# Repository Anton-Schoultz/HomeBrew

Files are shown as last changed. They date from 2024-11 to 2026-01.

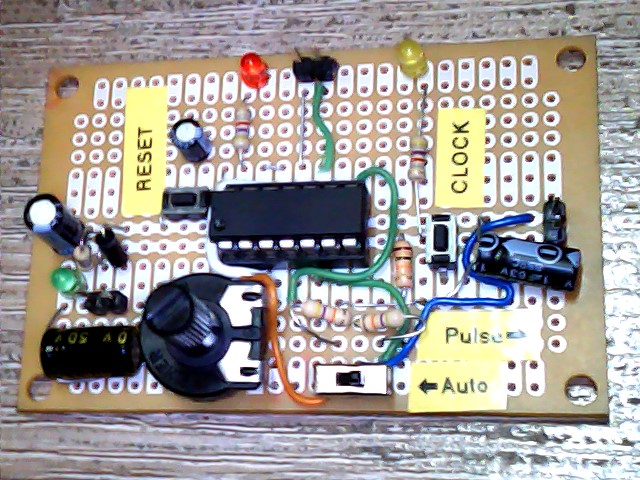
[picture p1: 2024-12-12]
Development/ClockCircuit/ClockCircuit.jpg

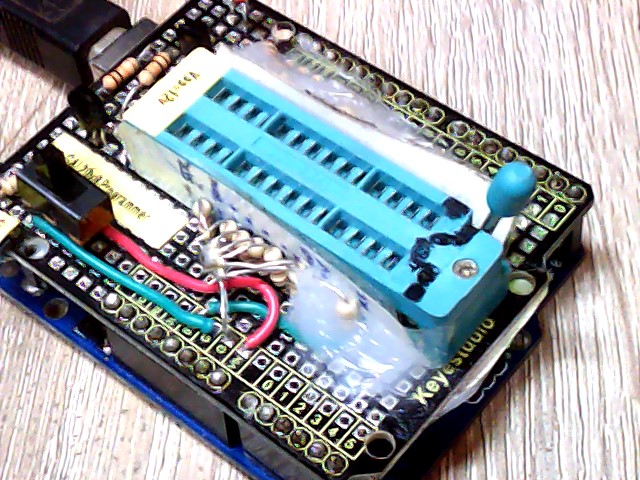
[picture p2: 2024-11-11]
Tools/GAL_Programmer/GAL_Programmer_Hat.jpg

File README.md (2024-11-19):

# HomeBrew
My attempt at rolling-my-own reto 80's home computer.

Aiming for a 6502 (specifically R65C02) based system,
ideally with video output.

# Tools
Here I have collected the various tools that I needed.
<br>See the README.md in the tools folder for more info.

## EE Programmer
Used to program the EEPROM that I use, the PQ 52B33, which is an 8K rom. 
Programmed via an arduino circuit, using java code on the pc side.

## GAL Programmer
Used to program the GAL20V8s that I use (available and affordable here).
<br>Bassed on the Afterburner project by Bruce Abbott.
<br>I added some convenience batch jobs GAL_Write.bat and GAL_Read.bat.

## Logic Analyser
Here I made use of the excellent PulseView Program,
using a Raspberry Pi Pico as the data capture device.

## WinCUPL
This outdated program from ATMEL is used to compile the fuse info for
programming the GAL20V8 chips.

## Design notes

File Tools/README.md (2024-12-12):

# Tools
A collection of the tools used for this project.

## GAL Programmer
The GAL programmer is bassed on this project by Bruce Abbott
https://github.com/ole00/afterburner/tree/version_4_legacy

## WinCUPL
This is used to program the GAL20v8 chips.

## Logic Analyser
Here I made use of the excellent PulseView Program,
using a Raspberry Pi Pico as the data capture device.

## EE Programmer
Simple DIY EEPROM programer for PQ 52B33 8k x 8 EEPROM (Using Arduino Nano)

## KiCAD
Schematic and PCB editor.

## IC Label Creator
This useful utility (from https://github.com/klemens-u/ic-label-creator) lets you print out IC-Labels.
You can define your own ICs and add them to the chips.js file.
I made some code changes so that it will print narrower to fit on top of the IC nicely,
also some changes to allow you to select your own border colour for the IC label.
I added IC pinouts for R65C02 (Cpu), 52B33 (8k EEPROM) ...

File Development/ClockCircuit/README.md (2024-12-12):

# Retro Computer
When I started on this journey to build my own retro computer I first looked to see what others had done.
I found Ben Eater's videos extremely useful.
I like his aproach to building his 6502 machine, and will most likely proceed in a similar fasion.

## Clock Circuit
After seeing the usefulness of Ben's clock circuit https://eater.net/8bit/clock, I opted to make my own.

I opted for a somewhat different (cruder) circuit, and added a reset circuit.

<image src="ClockCircuit.jpg"/>

Please excuse the hand-drawn diagram, but I figure even a badly hand drawn diagram is better than no diagram at all ;-)

The negative going reset pulse is generated at power-up, but can also be triggered by the push button.
<br>The positive going clock pulses can be manually generated, or auto-generated via a variable speed oscillator.
<br>It would probably be a good idea to add a 1K resistor in series with the variable resistor for safety..

<image src="CircuitDiagram.png"/>

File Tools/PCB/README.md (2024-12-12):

# KiCAD
Schematic and PCB editor.
Download the latest version from https://www.kicad.org/download/
(In my case, 8.0.6)

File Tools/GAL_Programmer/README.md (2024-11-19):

# GAL Programmer
The GAL programmer is bassed on this project by Bruce Abbott
https://github.com/ole00/afterburner/tree/version_4_legacy

<image src="afterburner_circuit.png"/>

The PC code is <a href="afterburner_w64_040.exe">afterburner w64 v4.0</a>
and the code for th Arduino UNO is <a href="afterburner042/afterburner042.ino">afterburner042.ino</a>

Links:
<br>https://www.youtube.com/watch?v=fCsP7ujMJV8

I used a circuit based on the one in the video (at 8:15)
to switch the 12v supply to the edit pin instead of the switchable module.

I thew it all together on a proto-typing 'hat' which then plugs onto the Arduino UNO R3.

<image src="GAL_Programmer_Hat.jpg"/>

<br>I added some convenience batch jobs GAL_Write.bat and GAL_Read.bat.

See also the section on WinCUPL (used to compile the descriptions)

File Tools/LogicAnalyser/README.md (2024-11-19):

# Logic Analyser
Here I made use of the excellent PulseView Program,
using a Raspberry Pi Pico as the data capture device.

*Raspberry Pi Install*

Hold down the button, plug it in, release the button.
It will appear as a USB drive, drag and drop this file
<code>pico_sdk_sigrok.uf2</code> into the folder to install the software
onto the Raspberry Pi.

As the Pi is 3v3 and I'm working with 5v circuits, I built a little adaptor board
with voltage dividers for the input pins.
I used 3k3 resistor in line, with a 4k7 to ground.

<image src="Pi-Pico-adapter-board.jpg"/>

I used the nightly builds as they include the Raspberry Pi capture device.
(The release version does not show it in the device dropdown)<ul>
<li><a href="pulseview-NIGHTLY-x86_64-release-installer.exe">Pulse View</a>
<li><a href="sigrok-cli-NIGHTLY-x86_64-release-installer.exe">Sigrok</a>
</ul>

Links: 
<br>https://www.youtube.com/watch?app=desktop&v=waBu6ijT3wo
<br>https://github.com/pysigrok/hardware-raspberrypi-pico

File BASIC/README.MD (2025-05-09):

<html><body>
<h1>BASIC 	KEYWORDS</H1>
<dl 		COMPACT>
<dt> 		ABS(##)<DD>RETURN absolute value of numeric expression ##
<dt> 		ASC($$)<DD>RETURN numeric value of the first character of String $$
<dt> 		CHR$(##)<DD>RETURN string with a character for the given value
<dt> 		CLEAR<DD>CLEAR variables
<dt> 		CLS<DD>CLEAR Screen
<dt> 		DEEK(##)<DD>RETURN the contents of memory word at address
<dt> 		dim 	a$(##size) [,b$(##size)]*<dd>Dimension Strings
<dt> 		DOKE 	##Address,##word<dd>Poke word of data to the address
<dt> 		for 	#V = ##From TO ##Limit [STEP ##Step]<dd>Start of FOR/NEXT Loop
<dt> 		FRE(##)<DD>RETURN number of bytes available in free memory
<dt> 		STR$(##Value)<DD>RETURN string representation of the value
<dt> 		GOSUB 	#expr<dd>Call subroutine at LineNo
<dt> 		GOTO 	#NumExpr<dd>Goto LineNo
<dt> 		IF 	?? THEN {Statment}<dd>Execute statement if condition ?? is true
<dt> 		DO 	string comparison
<dt> 		INPUT 	("prompt"|,|NumVar|StrVar)*<dd>Input values with optional prompts
<dt> 		LEFT$($$,##)<DD>KEEP left most chars of string [Head]
<dt> 		LEN($$)<DD>RETURN the length of the string expression
<dt> 		let 	{var}={expr}<dd>Assign value to a variable
<dt> 		LIST 	[##From] [- [##To]]<dd>List program (optional range of lines)
<dt> 		LIST 	lines in range LST_BEG to LST_END
<dt> 		LOAD<DD>LOAD program
<dt> 		LOWER($$)<DD>CONVERT string to Lower case
<dt> 		LTRIM($$)<DD>TRIM leading spaces from string
<dt> 		MID$($$,##From,##Len)<DD>RETURN substring of Len chars from position From
<dt> 		NEW<DD>CLEAR program and data
<dt> 		NEXT 	{Var}<dd>End of FOR/NEXT loop
<dt> 		PEEK(##Address)<DD>RETURN the byte at address
<dt> 		POKE 	##Address,##value<dd>Poke byte of data to the address
<dt> 		PRINT 	(##|$$| |,)*<dd>Print sequence of values
<dt> 		rem 	{comment}<dd>Program remarks/comments
<dt> 		RETURN<DD>RETURN control to after the GOSUB
<dt> 		RIGHT$($$,##N)<DD>KEEP right most N chars of string [Tail]
<dt> 		RND(##Max)<DD>RETURN random number 0..(##Max-)
<dt> 		RTRIM$($$)<DD>TRIM trailing spaces from string
<dt> 		run 	[#LineNo]<dd>Execute the program, optionally from line number
<dt> 		SAVE<DD>SAVE program
<dt> 		SGN(##Value)<DD>RETURN sign of the value as  -1, 0 or 1
<dt> 		SQR(##Val)<DD>RETURN the Square of Val
<dt> 		STOP<DD>STOP executing the program
<dt> 		TRIM$($$)<DD>TRIM leading and trailing spaces from the string
<dt> 		UPPER$($$)<DD>CONVERT string to upper case
<dt> 		VAL($$)<DD>EVALUATE the string and return it's numeric value
</dl>
<br>$$=String 	EXPRESSION
<br>##=Numeric 	EXPRESSION
<br>#=Numeric 	LITERAL
<br>$=String 	LITERAL (Quoted string)
<br>??=Relational/Conditional EXPRESSION
</body>
</html>

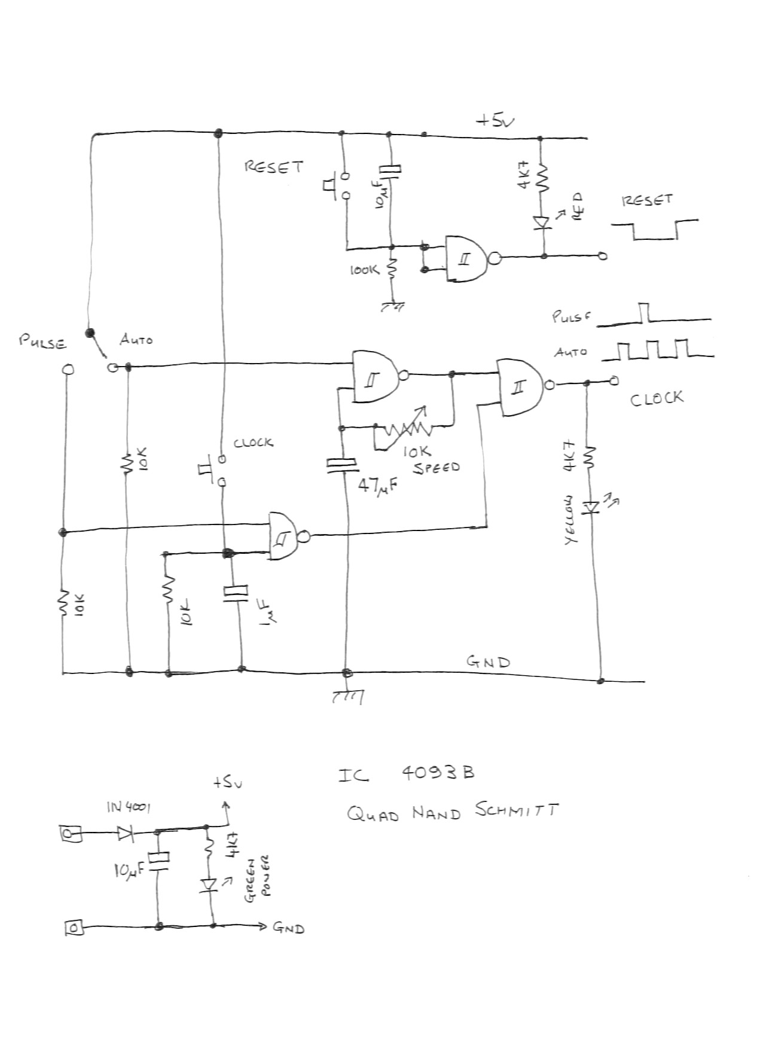
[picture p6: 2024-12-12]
Development/ClockCircuit/CircuitDiagram.png

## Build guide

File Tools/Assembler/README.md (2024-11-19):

# Assembler
I use <a href="https://jorgicor.niobe.org/uz80as/">this</a>
assembler (originally for Z80) but has R65C02 as a valid target.
I use Ultra Edit as the editor, and add 'Tools' to call the assembler as needed.

## Simulator
There is also a 6502 based IDE including a simulator,
See 6502_Simulator section

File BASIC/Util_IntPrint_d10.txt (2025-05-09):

;=================================================================== UTIL_INT ========= 
; IntParse:; parse an integer
IntPrint: ; Print integer AX to mem/io via PutChr
; 65535:2276c, 10000:2246, 1000:1781
 		sta 	ZTMP
 		stx 	ZTMP+1
 		ldy 	#$FF
 		phy 				; marker on the stack
IntPrint1 	jsr 	IntDT 			; ZTMP /= 10, remainder in A
 		ora 	#'0'
 		pha 				; push the digit
 		lda 	ZTMP 			; done?
 		ora 	ZTMP+1
 		bne 	IntPrint1 		; no- loop
 		;-- 
IntPrint2 	;- now pop & print the digits
 		pla
 		bmi 	IntPrintX 		; found the marker so exit
 		jsr 	PutChr
 		bra 	IntPrint2
IntPrintX 	rts

;------------------------------------------------------- IntDT_AX 
IntDT_AX: ; Divide AX by 10, result in ZTMP, remainder in A
 		sta 	ZTMP
 		stx 	ZTMP+1
 		;-- fall through
IntDT: ; Divide ZTMP by 10, remainder in A
 		ldx 	#16
 		lda 	#0
IntDT_AX1 	asl 	ZTMP
 		rol 	ZTMP+1
 		rol 	a
 		cmp 	#10
 		bcc 	IntDT_AX2
 		sbc 	#10
 		inc 	ZTMP
IntDT_AX2 	dex
 		bne 	IntDT_AX1
 		rts

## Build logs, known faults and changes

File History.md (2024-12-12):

# History

## 2024

**October**
GAL Programmer, WinCUPL
Simple EE prgrammer on breadboard.

**November**
Assembler, 6502 Simulator, PCB software (KiCAD)

**December**
Logic Analyser.
<br>Built my clock circuit
<br>some test code on Arduino Mega to 'talk' to a 240x128 LCD screen.

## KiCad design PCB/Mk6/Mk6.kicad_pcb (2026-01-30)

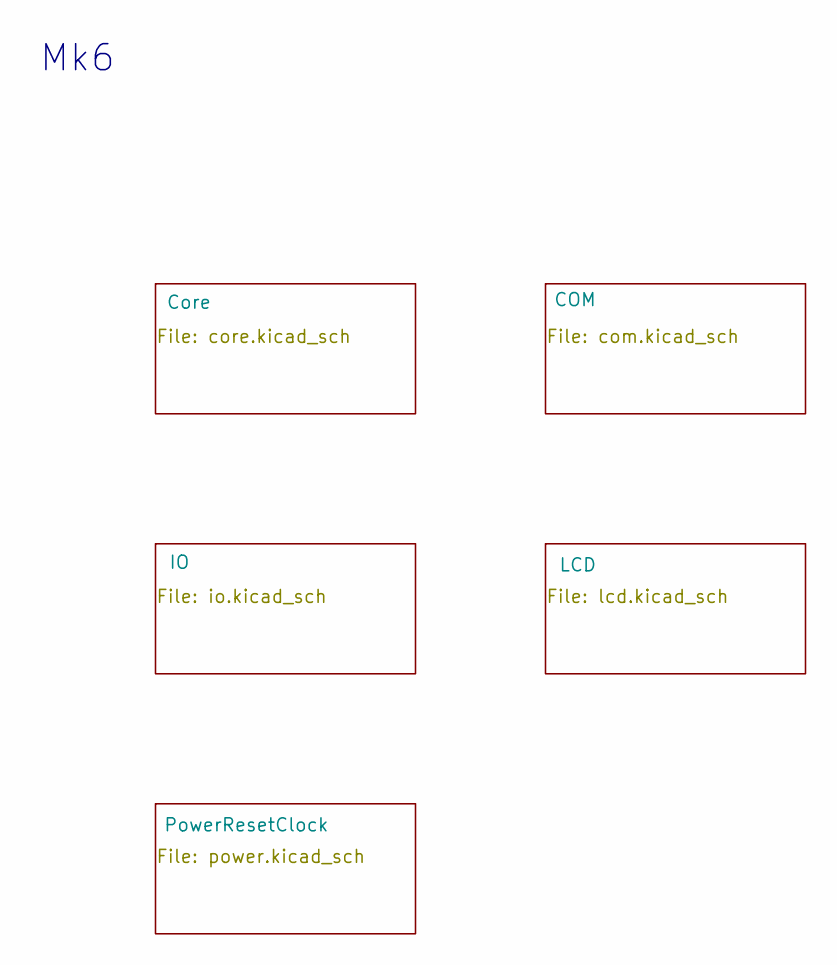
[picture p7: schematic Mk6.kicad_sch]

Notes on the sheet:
Mk6

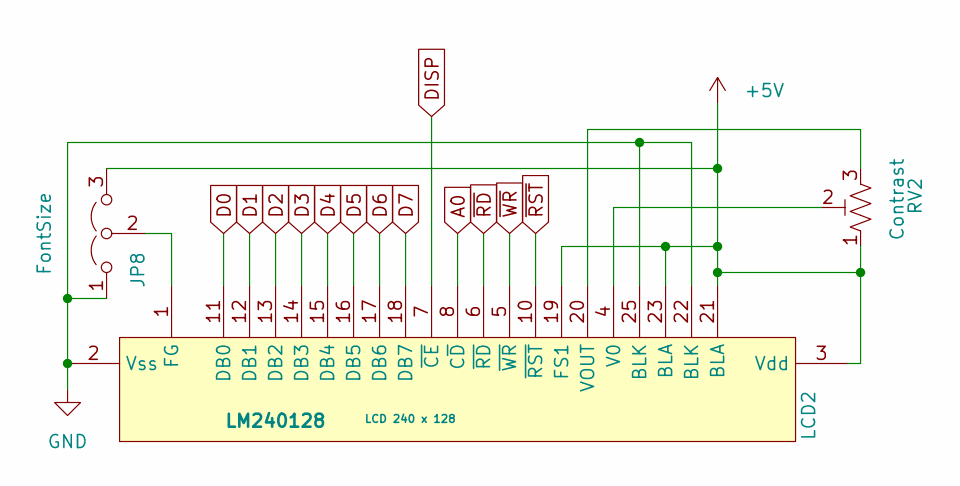
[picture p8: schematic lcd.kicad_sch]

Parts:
JP8: FontSize; PinHeader_1x03_P2.54mm_Vertical
LCD2: LM240128; LCD 240x128
RV2: Contrast; Potentiometer_Piher_PT-15-V15_Vertical

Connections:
+5V: JP8.3 (B), LCD2.3 (Vdd), LCD2.19 (FS1), LCD2.21 (BLA), LCD2.23 (BLA), RV2.1; also elsewhere on the board
A0: LCD2.8 (C~D); also elsewhere on the board
D0: LCD2.11 (DB0); also elsewhere on the board
D1: LCD2.12 (DB1); also elsewhere on the board
D2: LCD2.13 (DB2); also elsewhere on the board
D3: LCD2.14 (DB3); also elsewhere on the board
D4: LCD2.15 (DB4); also elsewhere on the board
D5: LCD2.16 (DB5); also elsewhere on the board
D6: LCD2.17 (DB6); also elsewhere on the board
D7: LCD2.18 (DB7); also elsewhere on the board
DISP: LCD2.7 (~CE); also elsewhere on the board
GND: JP8.1 (A), LCD2.2 (Vss), LCD2.22 (BLK), LCD2.25 (BLK); also elsewhere on the board
unnamed: JP8.2 (C), LCD2.1 (FG)
unnamed: LCD2.4 (V0), RV2.2
unnamed: LCD2.20 (VOUT), RV2.3
~RD: LCD2.6 (~RD); also elsewhere on the board
~RST: LCD2.10 (~RST); also elsewhere on the board
~WR: LCD2.5 (~WR); also elsewhere on the board

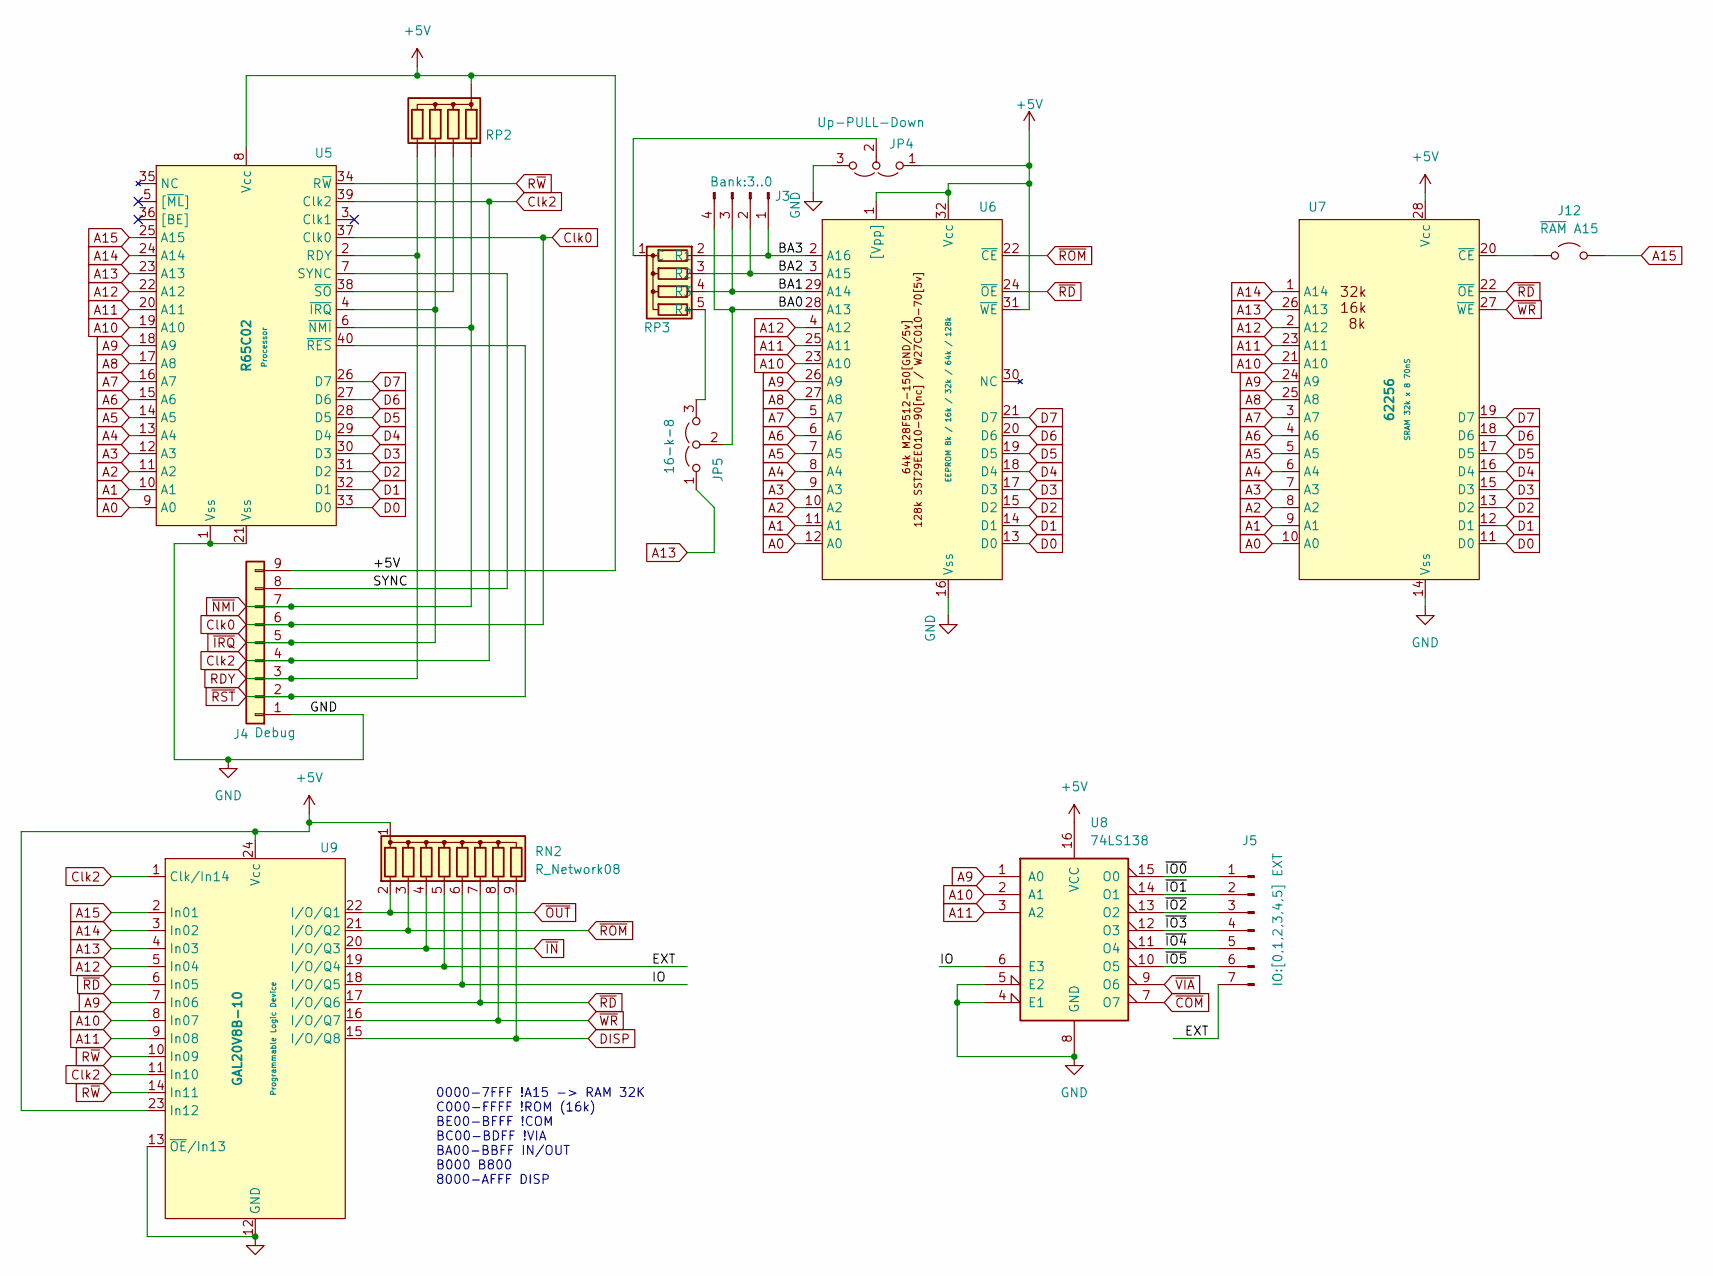
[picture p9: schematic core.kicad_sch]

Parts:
J3: Bank:3..0; PinHeader_1x04_P2.54mm_Vertical
J4: Debug; PinHeader_1x09_P2.54mm_Vertical
J5: IO:[0,1,2,3,4,5] EXT; PinSocket_1x07_P2.54mm_Vertical
J12: ~{RAM} A15; PinHeader_1x02_P2.54mm_Vertical
JP4: Up-PULL-Down; PinHeader_1x03_P2.54mm_Vertical
JP5: 16-k-8; PinHeader_1x03_P2.54mm_Vertical
RN2: R_Network08; R_Array_SIP9
RP2, RP3: R_Array_SIP5
U5: R65C02; DIP-40_W15.24mm_LongPads
U6: EEPROM; DIP_Socket-32_W11.9_W12.7_W15.24_W17.78_W18.5_3M_232-1285-0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
U7: 62256; DIP-28_W15.24mm_LongPads
U8: 74LS138; DIP-16_W7.62mm_LongPads
U9: GAL20V8B-10; DIP-24_W7.62mm_LongPads

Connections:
+5V: J4.9, JP4.1 (A), RN2.1 (common), RP2.1 (C), U5.8 (Vcc), U6.1 ([Vpp]), U6.31 (~WE), U6.32 (Vcc), U7.28 (Vcc), U8.16 (VCC), U9.23 (In12), U9.24 (Vcc); also elsewhere on the board
/Core/BA0: J3.4, JP5.2 (C), U6.28 (A13)
/Core/BA1: J3.3, RP3.4 (R3), U6.29 (A14)
/Core/BA2: J3.2, RP3.3 (R2), U6.3 (A15)
/Core/BA3: J3.1, RP3.2 (R1), U6.2 (A16)
/Core/EXT: J5.7, RN2.5 (R4), U9.19 (I/O/Q4)
/Core/IO: RN2.6 (R5), U8.6 (E3), U9.18 (I/O/Q5)
/Core/SYNC: J4.8, U5.7 (SYNC)
/Core/~IO0: J5.1, U8.15 (O0)
/Core/~IO1: J5.2, U8.14 (O1)
/Core/~IO2: J5.3, U8.13 (O2)
/Core/~IO3: J5.4, U8.12 (O3)
/Core/~IO4: J5.5, U8.11 (O4)
/Core/~IO5: J5.6, U8.10 (O5)
A0: U5.9 (A0), U6.12 (A0), U7.10 (A0); also elsewhere on the board
A1: U5.10 (A1), U6.11 (A1), U7.9 (A1); also elsewhere on the board
A2: U5.11 (A2), U6.10 (A2), U7.8 (A2); also elsewhere on the board
A3: U5.12 (A3), U6.9 (A3), U7.7 (A3); also elsewhere on the board
A4: U5.13 (A4), U6.8 (A4), U7.6 (A4); also elsewhere on the board
A5: U5.14 (A5), U6.7 (A5), U7.5 (A5); also elsewhere on the board
A6: U5.15 (A6), U6.6 (A6), U7.4 (A6); also elsewhere on the board
A7: U5.16 (A7), U6.5 (A7), U7.3 (A7); also elsewhere on the board
A8: U5.17 (A8), U6.27 (A8), U7.25 (A8); also elsewhere on the board
A9: U5.18 (A9), U6.26 (A9), U7.24 (A9), U8.1 (A0), U9.7 (In06); also elsewhere on the board
A10: U5.19 (A10), U6.23 (A10), U7.21 (A10), U8.2 (A1), U9.8 (In07); also elsewhere on the board
A11: U5.20 (A11), U6.25 (A11), U7.23 (A11), U8.3 (A2), U9.9 (In08); also elsewhere on the board
A12: U5.22 (A12), U6.4 (A12), U7.2 (A12), U9.5 (In04); also elsewhere on the board
A13: JP5.1 (A), U5.23 (A13), U7.26 (A13), U9.4 (In03)
A14: U5.24 (A14), U7.1 (A14), U9.3 (In02)
A15: J12.2 (B), U5.25 (A15), U9.2 (In01)
Clk0: J4.6, U5.37 (Clk0); also elsewhere on the board
Clk2: J4.4, U5.39 (Clk2), U9.1 (Clk/In14), U9.11 (In10); also elsewhere on the board
D0: U5.33 (D0), U6.13 (D0), U7.11 (D0); also elsewhere on the board
D1: U5.32 (D1), U6.14 (D1), U7.12 (D1); also elsewhere on the board
D2: U5.31 (D2), U6.15 (D2), U7.13 (D2); also elsewhere on the board
D3: U5.30 (D3), U6.17 (D3), U7.15 (D3); also elsewhere on the board
D4: U5.29 (D4), U6.18 (D4), U7.16 (D4); also elsewhere on the board
D5: U5.28 (D5), U6.19 (D5), U7.17 (D5); also elsewhere on the board
D6: U5.27 (D6), U6.20 (D6), U7.18 (D6); also elsewhere on the board
D7: U5.26 (D7), U6.21 (D7), U7.19 (D7); also elsewhere on the board
DISP: RN2.9 (R8), U9.15 (I/O/Q8); also elsewhere on the board
GND: J4.1, JP4.3 (B), U5.1 (Vss), U5.21 (Vss), U6.16 (Vss), U7.14 (Vss), U8.4 (E1), U8.5 (E2), U8.8 (GND), U9.12 (GND), U9.13 (~OE/In13); also elsewhere on the board
unnamed: J12.1 (A), U7.20 (~CE)
unnamed: JP4.2 (C), RP3.1 (C)
unnamed: JP5.3 (B), RP3.5 (R4)
unnamed: RP2.3 (R2), U5.38 (~SO)
RDY: J4.3, RP2.5 (R4), U5.2 (RDY); also elsewhere on the board
R~W: U5.34 (R~W), U9.10 (In09), U9.14 (In11); also elsewhere on the board
~COM: U8.7 (O7); also elsewhere on the board
~IN: RN2.4 (R3), U9.20 (I/O/Q3); also elsewhere on the board
~IRQ: J4.5, RP2.4 (R3), U5.4 (~IRQ); also elsewhere on the board
~NMI: J4.7, RP2.2 (R1), U5.6 (~NMI); also elsewhere on the board
~OUT: RN2.2 (R1), U9.22 (I/O/Q1); also elsewhere on the board
~RD: RN2.7 (R6), U6.24 (~OE), U7.22 (~OE), U9.6 (In05), U9.17 (I/O/Q6); also elsewhere on the board
~ROM: RN2.3 (R2), U6.22 (~CE), U9.21 (I/O/Q2)
~RST: J4.2, U5.40 (~RES); also elsewhere on the board
~VIA: U8.9 (O6); also elsewhere on the board
~WR: RN2.8 (R7), U7.27 (~WE), U9.16 (I/O/Q7); also elsewhere on the board

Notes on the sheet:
0000-7FFF !A15 -> RAM 32K C000-FFFF !ROM (16k) BE00-BFFF !COM BC00-BDFF !VIA BA00-BBFF IN/OUT B000 B800 8000-AFFF DISP

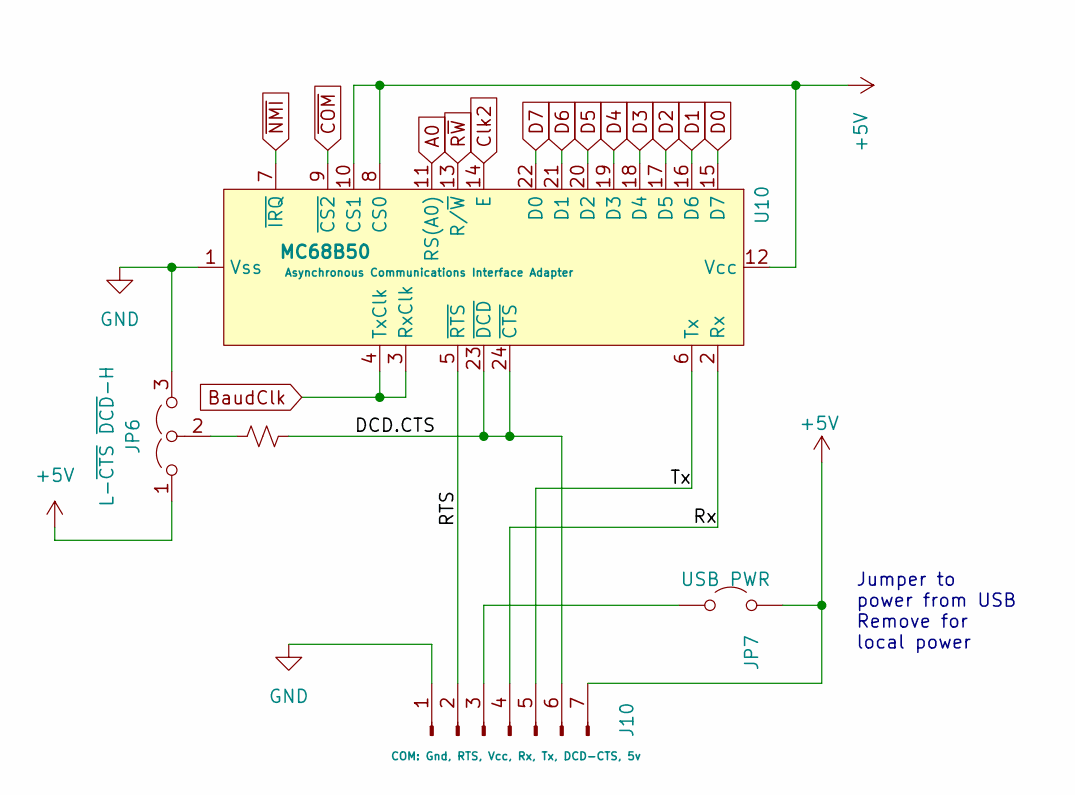
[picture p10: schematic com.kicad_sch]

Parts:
J10: COM: Gnd, RTS, Vcc, Rx, Tx, DCD-CTS, 5v; PinSocket_1x07_P2.54mm_Horizontal
JP6: L-~{CTS} ~{DCD}-H; PinHeader_1x03_P2.54mm_Vertical
JP7: USB PWR; PinHeader_1x02_P2.54mm_Vertical
R4: PUp; R_Axial_DIN0204_L3.6mm_D1.6mm_P7.62mm_Horizontal
U10: MC68B50; DIP-24_W15.24mm_LongPads

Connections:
+5V: J10.7, JP6.1 (A), JP7.2 (B), U10.8 (CS0), U10.10 (CS1), U10.12 (Vcc); also elsewhere on the board
/COM/DCD.CTS: J10.6, R4.2, U10.23 (~DCD), U10.24 (~CTS)
/COM/RTS: J10.2, U10.5 (~RTS)
/COM/Rx: J10.4, U10.2 (Rx)
/COM/Tx: J10.5, U10.6 (Tx)
A0: U10.11 (RS(A0)); also elsewhere on the board
BaudClk: U10.3 (RxClk), U10.4 (TxClk); also elsewhere on the board
Clk2: U10.14 (E); also elsewhere on the board
D0: U10.15 (D7); also elsewhere on the board
D1: U10.16 (D6); also elsewhere on the board
D2: U10.17 (D5); also elsewhere on the board
D3: U10.18 (D4); also elsewhere on the board
D4: U10.19 (D3); also elsewhere on the board
D5: U10.20 (D2); also elsewhere on the board
D6: U10.21 (D1); also elsewhere on the board
D7: U10.22 (D0); also elsewhere on the board
GND: J10.1, JP6.3 (B), U10.1 (Vss); also elsewhere on the board
unnamed: J10.3, JP7.1 (A)
unnamed: JP6.2 (C), R4.1
R~W: U10.13 (R/~W); also elsewhere on the board
~COM: U10.9 (~CS2); also elsewhere on the board
~NMI: U10.7 (~IRQ); also elsewhere on the board

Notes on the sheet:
Jumper to power from USB Remove for local power

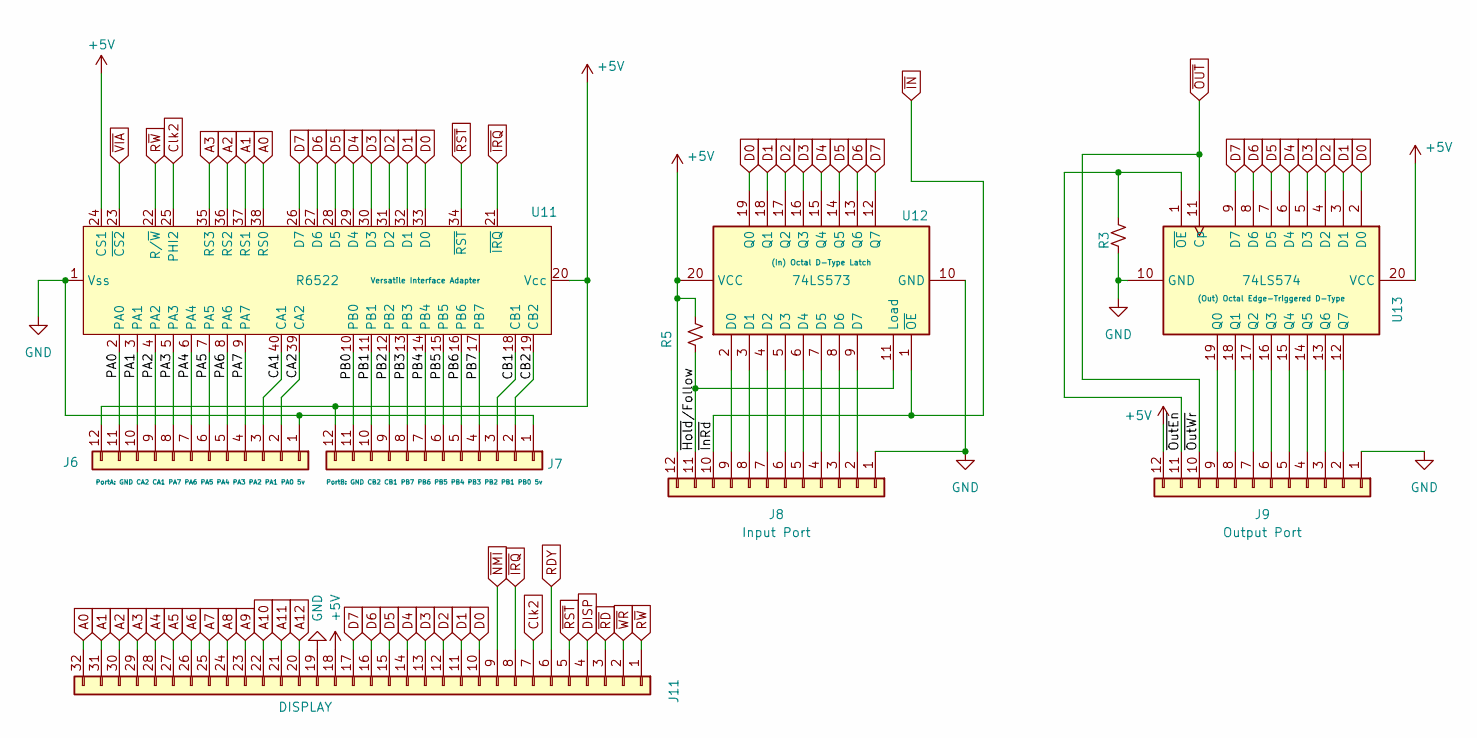
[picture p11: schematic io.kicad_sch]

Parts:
J6: PortA: GND CA2 CA1 PA7 PA6 PA5 PA4 PA3 PA2 PA1 PA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; PinSocket_1x12_P2.54mm_Vertical
J7: PortB: GND CB2 CB1 PB7 PB6 PB5 PB4 PB3 PB2 PB1 PB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; PinSocket_1x12_P2.54mm_Vertical
J8: Input Port; PinHeader_1x12_P2.54mm_Vertical
J9: Output Port; PinHeader_1x12_P2.54mm_Vertical
J11: DISPLAY; PinSocket_1x32_P2.54mm_Vertical
R3, R5: R_Small_US; R_Axial_DIN0204_L3.6mm_D1.6mm_P7.62mm_Horizontal
U11: R6522; DIP-40_W15.24mm_LongPads
U12: 74LS573; DIP-20_W7.62mm_LongPads
U13: 74LS574; DIP-20_W7.62mm_LongPads

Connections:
+5V: J6.12, J7.12, J8.12, J9.12, J11.18, R5.1, U11.20 (Vcc), U11.24 (CS1), U12.20 (VCC), U13.20 (VCC); also elsewhere on the board
/IO/CA1: J6.3, U11.40 (CA1)
/IO/CA2: J6.2, U11.39 (CA2)
/IO/CB1: J7.3, U11.18 (CB1)
/IO/CB2: J7.2, U11.19 (CB2)
/IO/PA0: J6.11, U11.2 (PA0)
/IO/PA1: J6.10, U11.3 (PA1)
/IO/PA2: J6.9, U11.4 (PA2)
/IO/PA3: J6.8, U11.5 (PA3)
/IO/PA4: J6.7, U11.6 (PA4)
/IO/PA5: J6.6, U11.7 (PA5)
/IO/PA6: J6.5, U11.8 (PA6)
/IO/PA7: J6.4, U11.9 (PA7)
/IO/PB0: J7.11, U11.10 (PB0)
/IO/PB1: J7.10, U11.11 (PB1)
/IO/PB2: J7.9, U11.12 (PB2)
/IO/PB3: J7.8, U11.13 (PB3)
/IO/PB4: J7.7, U11.14 (PB4)
/IO/PB5: J7.6, U11.15 (PB5)
/IO/PB6: J7.5, U11.16 (PB6)
/IO/PB7: J7.4, U11.17 (PB7)
/IO/~Hold/Follow: J8.11, R5.2, U12.11 (Load)
/IO/~OutEn: J9.11, R3.2, U13.1 (~OE)
A0: J11.32, U11.38 (RS0); also elsewhere on the board
A1: J11.31, U11.37 (RS1); also elsewhere on the board
A2: J11.30, U11.36 (RS2); also elsewhere on the board
A3: J11.29, U11.35 (RS3); also elsewhere on the board
A4: J11.28; also elsewhere on the board
A5: J11.27; also elsewhere on the board
A6: J11.26; also elsewhere on the board
A7: J11.25; also elsewhere on the board
A8: J11.24; also elsewhere on the board
A9: J11.23; also elsewhere on the board
A10: J11.22; also elsewhere on the board
A11: J11.21; also elsewhere on the board
A12: J11.20; also elsewhere on the board
Clk2: J11.7, U11.25 (PHI2); also elsewhere on the board
D0: J11.10, U11.33 (D0), U12.19 (Q0), U13.2 (D0); also elsewhere on the board
D1: J11.11, U11.32 (D1), U12.18 (Q1), U13.3 (D1); also elsewhere on the board
D2: J11.12, U11.31 (D2), U12.17 (Q2), U13.4 (D2); also elsewhere on the board
D3: J11.13, U11.30 (D3), U12.16 (Q3), U13.5 (D3); also elsewhere on the board
D4: J11.14, U11.29 (D4), U12.15 (Q4), U13.6 (D4); also elsewhere on the board
D5: J11.15, U11.28 (D5), U12.14 (Q5), U13.7 (D5); also elsewhere on the board
D6: J11.16, U11.27 (D6), U12.13 (Q6), U13.8 (D6); also elsewhere on the board
D7: J11.17, U11.26 (D7), U12.12 (Q7), U13.9 (D7); also elsewhere on the board
DISP: J11.4; also elsewhere on the board
GND: J6.1, J7.1, J8.1, J9.1, J11.19, R3.1, U11.1 (Vss), U12.10 (GND), U13.10 (GND); also elsewhere on the board
unnamed: J8.2, U12.9 (D7)
unnamed: J8.3, U12.8 (D6)
unnamed: J8.4, U12.7 (D5)
unnamed: J8.5, U12.6 (D4)
unnamed: J8.6, U12.5 (D3)
unnamed: J8.7, U12.4 (D2)
unnamed: J8.8, U12.3 (D1)
unnamed: J8.9, U12.2 (D0)
unnamed: J9.2, U13.12 (Q7)
unnamed: J9.3, U13.13 (Q6)
unnamed: J9.4, U13.14 (Q5)
unnamed: J9.5, U13.15 (Q4)
unnamed: J9.6, U13.16 (Q3)
unnamed: J9.7, U13.17 (Q2)
unnamed: J9.8, U13.18 (Q1)
unnamed: J9.9, U13.19 (Q0)
RDY: J11.6; also elsewhere on the board
R~W: J11.1, U11.22 (R/~W); also elsewhere on the board
~IN: J8.10, U12.1 (~OE); also elsewhere on the board
~IRQ: J11.8, U11.21 (~IRQ); also elsewhere on the board
~NMI: J11.9; also elsewhere on the board
~OUT: J9.10, U13.11 (Cp); also elsewhere on the board
~RD: J11.3; also elsewhere on the board
~RST: J11.5, U11.34 (~RST); also elsewhere on the board
~VIA: U11.23 (~CS2); also elsewhere on the board
~WR: J11.2; also elsewhere on the board

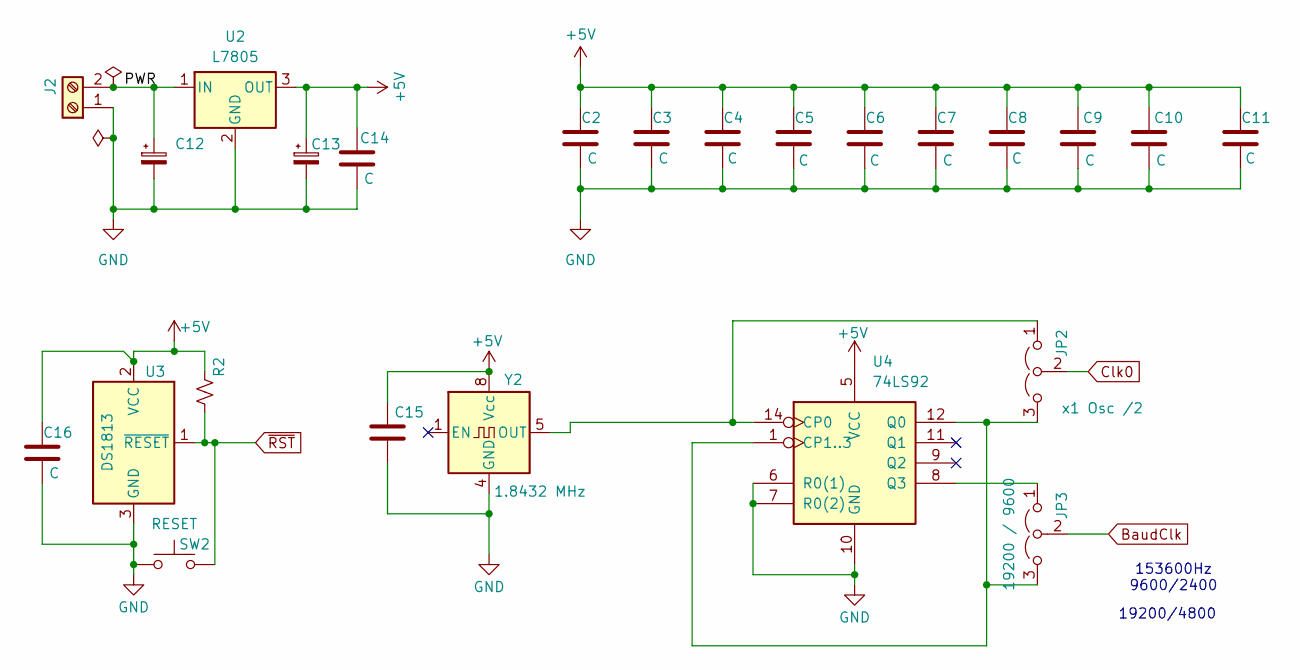
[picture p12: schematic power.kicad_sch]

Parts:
C2, C3, C4, C5, C6, C7, C8, C9, C10, C11, C14, C15, C16: C; C_Disc_D7.5mm_W2.5mm_P5.00mm
C12, C13: C_Polarized_Small; CP_Radial_D10.0mm_P7.50mm
J2: Power; TerminalBlock_MaiXu_MX126-5.0-02P_1x02_P5.00mm
JP2: x1 Osc /2; PinHeader_1x03_P2.54mm_Vertical
JP3: 19200 / 9600; PinHeader_1x03_P2.54mm_Vertical
R2: R_Small_US; R_Axial_DIN0204_L3.6mm_D1.6mm_P7.62mm_Horizontal
SW2: RESET; SW_PUSH_1P1T_6x3.5mm_H4.3_APEM_MJTP1243
U2: L7805; TO-220-3_Vertical
U3: DS1813; TO-92L_Wide
U4: 74LS92; DIP-14_W7.62mm_LongPads
Y2: 1.8432 MHz; Oscillator_DIP-8

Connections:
+5V: C2.1, C3.1, C4.1, C5.1, C6.1, C7.1, C8.1, C9.1, C10.1, C11.1, C13.1, C14.1, C15.1, C16.1, R2.1, U2.3 (OUT), U3.2 (VCC), U4.5 (VCC), Y2.8 (Vcc); also elsewhere on the board
/PowerResetClock/PWR: C12.1, J2.2, U2.1 (IN)
BaudClk: JP3.2 (C); also elsewhere on the board
Clk0: JP2.2 (C); also elsewhere on the board
GND: C2.2, C3.2, C4.2, C5.2, C6.2, C7.2, C8.2, C9.2, C10.2, C11.2, C12.2, C13.2, C14.2, C15.2, C16.2, J2.1, SW2.1, U2.2 (GND), U3.3 (GND), U4.6 (R0(1)), U4.7 (R0(2)), U4.10 (GND), Y2.4 (GND); also elsewhere on the board
unnamed: JP2.1 (A), U4.14 (CP0), Y2.5 (OUT)
unnamed: JP2.3 (B), JP3.3 (B), U4.1 (CP1..3), U4.12 (Q0)
unnamed: JP3.1 (A), U4.8 (Q3)
~RST: R2.2, SW2.2, U3.1 (~RESET); also elsewhere on the board

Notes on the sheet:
153600Hz 9600/2400
19200/4800

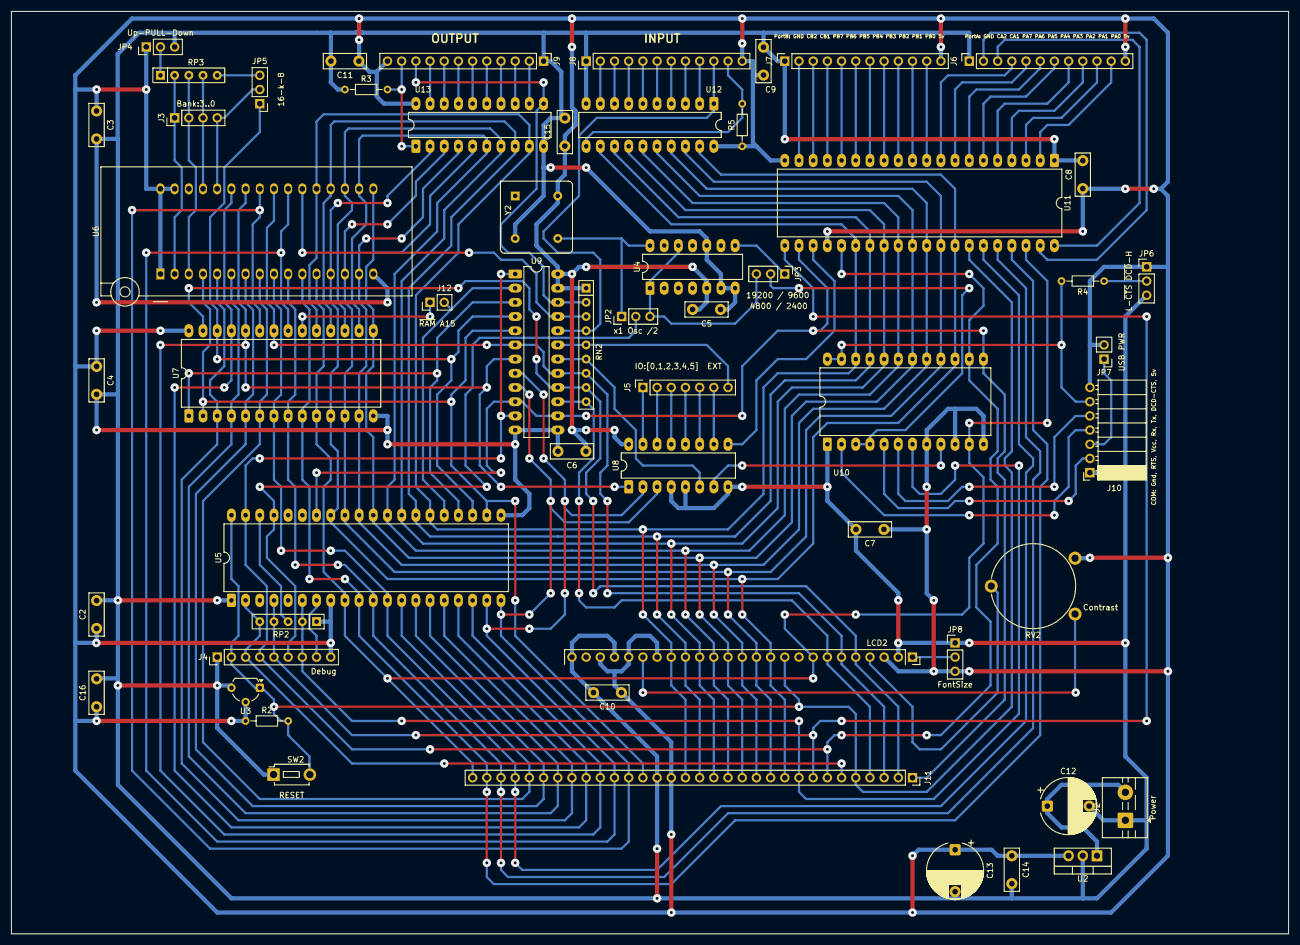
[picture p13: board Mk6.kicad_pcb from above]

Board: 2 copper layers, 228.6 x 165.1 mm, 56 parts (0 on the bottom side), 110 nets.

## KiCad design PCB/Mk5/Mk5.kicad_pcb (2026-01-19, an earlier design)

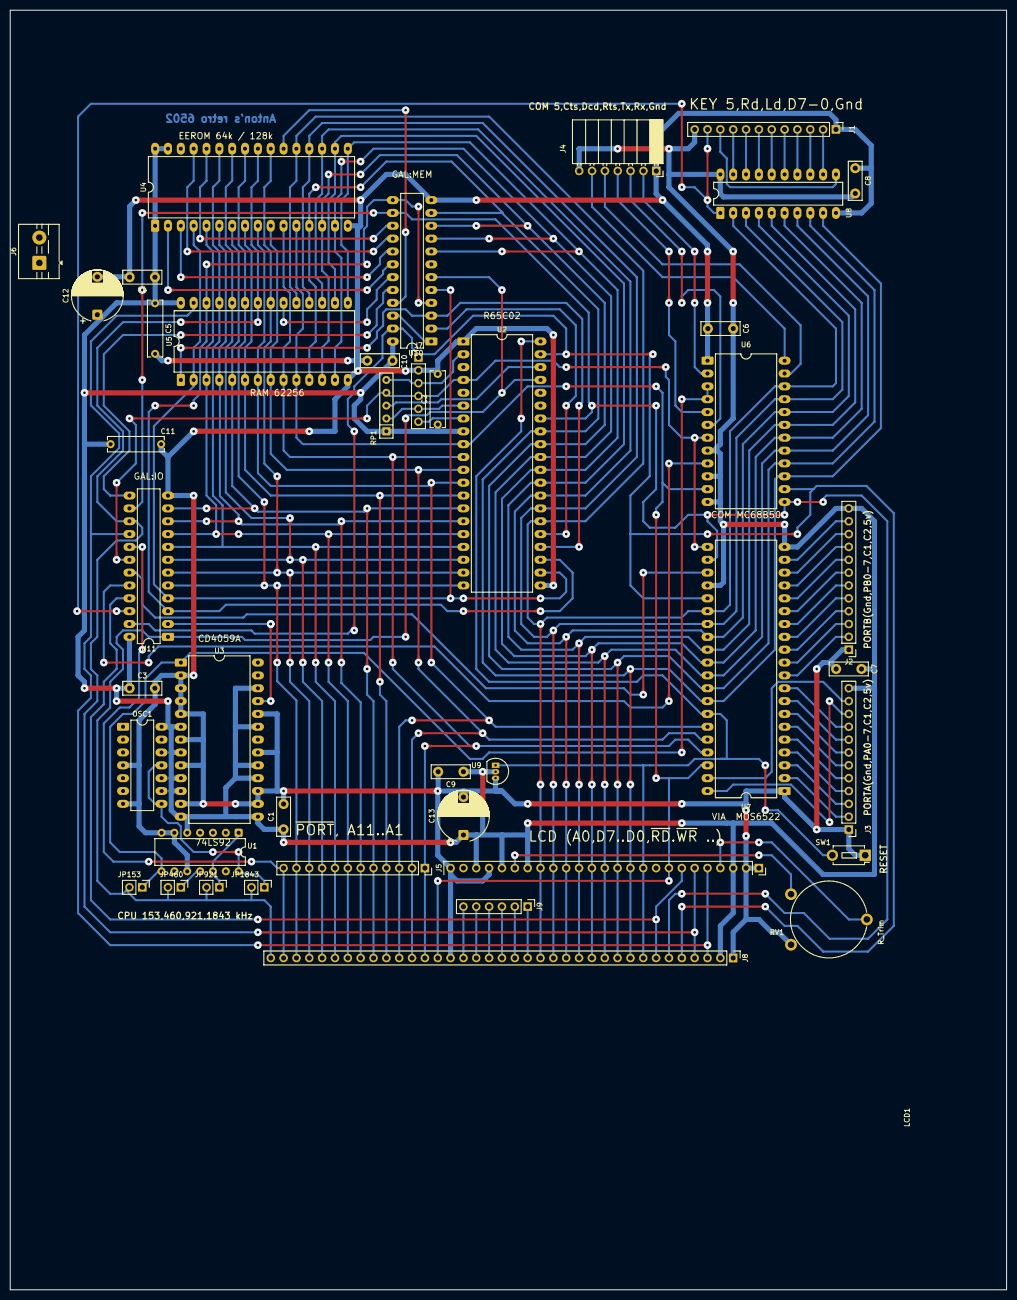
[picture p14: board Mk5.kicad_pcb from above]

Board: 2 copper layers, 197.0 x 253.0 mm, 42 parts (0 on the bottom side), 97 nets.

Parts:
C1, C3, C4, C6, C7, C8, C9, C10: C; C_Disc_D7.5mm_W2.5mm_P5.00mm
C2, C5, C11: C; C_Rect_L11.0mm_W2.8mm_P10.00mm_MKT
C12, C13: C_Polarized_Small; CP_Radial_D10.0mm_P7.50mm
J1: KeyBoard 5,Rd,Ld,D7..0,Gnd; PinHeader_1x12_P2.54mm_Vertical
J2: PortB; PinHeader_1x12_P2.54mm_Vertical
J3: PortA; PinHeader_1x12_P2.54mm_Vertical
J4: COM: Gnd,Rx,Tx,Rts,Dcd,Cts,5v; PinSocket_1x07_P2.54mm_Horizontal
J5: Conn_01x12; PinSocket_1x12_P2.54mm_Vertical
J6: Screw_Terminal_01x02; TerminalBlock_MaiXu_MX126-5.0-02P_1x02_P5.00mm
J7, J9: Conn_01x06_Pin; PinHeader_1x06_P2.54mm_Vertical
J8: Conn_01x37_Pin; PinHeader_1x37_P2.54mm_Vertical
JP153, JP460, JP921, JP1843: Jumper_2_Open; PinHeader_1x02_P2.54mm_Vertical
LCD1: LM240128; LCD 240x128
OSC1: DIP-14_W7.62mm_LongPads
RP1: R_Array_SIP5
RV1: R_Trim; Potentiometer_Piher_PT-15-V15_Vertical
SW1: RST; SW_PUSH_1P1T_6x3.5mm_H4.3_APEM_MJTP1243
U1: 74LS92; DIP-14_W7.62mm
U2: R65C02; DIP-40_W15.24mm_LongPads
U3: CD4059A; DIP-26_W15.24mm_LongPads
U4: EEPROM; DIP-32_W15.24mm_LongPads
U5: 62256; DIP-28_W15.24mm_LongPads
U6: MC68B50; DIP-24_W15.24mm_LongPads
U7: R6522; DIP-40_W15.24mm_LongPads
U8: 74LS573; DIP-20_W7.62mm_LongPads
U9: DS1813; TO-92L_Inline
U10, U11: GAL20V8B-10; DIP-24_W7.62mm_LongPads

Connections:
+5V: C1.1, C2.1, C3.1, C4.1, C5.1, C6.1, C7.1, C8.1, C9.1, C10.1, C11.1, C12.1, C13.1, J1.12, J2.12, J3.12, J4.7, J6.2, J8.2, LCD1.3 (Vdd), LCD1.19 (FS1), LCD1.21 (BLA), LCD1.23 (BLA), OSC1.14 (Vcc), RP1.1 (C), U1.5 (VCC), U2.8 (Vcc), U3.6 (R8.J4), U3.8 (J15.H4), U3.10 (J13.H1), U3.11 (Kc), U3.13 (Kb), U3.14 (Ka), U3.17 (J10.T2), U3.18 (J09.T1), U3.20 (J07.U4), U3.21 (J06.U2), U3.24 (Vcc), U4.1 ([Vpp]), U4.31 (~WE), U4.32 (Vcc), U5.28 (Vcc), U6.8 (CS0), U6.10 (CS1), U6.12 (Vcc), U7.20 (Vcc), U7.24 (CS1), U8.20 (VCC), U9.2 (VCC), U10.24 (Vcc), U11.24 (Vcc)
/A0: J8.24, LCD1.8 (C~D), U2.9 (A0), U4.12 (A0), U5.10 (A0), U6.11 (RS(A0)), U7.38 (RS0)
/A1: J5.1, J8.25, U2.10 (A1), U4.11 (A1), U5.9 (A1), U7.37 (RS1)
/A2: J5.2, J8.26, U2.11 (A2), U4.10 (A2), U5.8 (A2), U7.36 (RS2)
/A3: J5.3, J8.27, U2.12 (A3), U4.9 (A3), U5.7 (A3), U7.35 (RS3)
/A4: J5.4, J8.28, U2.13 (A4), U4.8 (A4), U5.6 (A4)
/A5: J5.5, J8.29, U2.14 (A5), U4.7 (A5), U5.5 (A5), U11.11 (In10)
/A6: J5.6, J8.30, U2.15 (A6), U4.6 (A6), U5.4 (A6), U11.10 (In09)
/A7: J5.7, J8.31, U2.16 (A7), U4.5 (A7), U5.3 (A7), U11.9 (In08)
/A8: J5.8, J8.32, U2.17 (A8), U4.27 (A8), U5.25 (A8), U11.8 (In07)
/A9: J5.9, J8.33, U2.18 (A9), U4.26 (A9), U5.24 (A9), U11.7 (In06)
/A10: J5.10, J8.34, U2.19 (A10), U4.23 (A10), U5.21 (A10), U11.6 (In05)
/A11: J5.11, J8.35, U2.20 (A11), U4.25 (A11), U5.23 (A11), U11.5 (In04)
/A12: U2.22 (A12), U4.4 (A12), U5.2 (A12), U10.5 (In04), U11.4 (In03)
/A13: U2.23 (A13), U5.26 (A13), U10.4 (In03), U10.13 (~OE/In13), U11.3 (In02)
/A14: U2.24 (A14), U5.1 (A14), U10.3 (In02)
/A15: U2.25 (A15), U10.2 (In01)
/BA0: U4.28 (A13), U10.15 (I/O/Q8)
/BA1: U4.29 (A14), U10.16 (I/O/Q7)
/BA2: U4.3 (A15), U10.17 (I/O/Q6)
/BA3: U4.2 (A16), U10.18 (I/O/Q5)
/BankWr: U10.1 (Clk/In14), U10.22 (I/O/Q1)
/BaudClk: JP153.1 (A), U1.8 (Q3), U3.1 (CLK), U6.3 (RxClk), U6.4 (TxClk)
/Clk0: J8.37, JP153.2 (B), JP460.2 (B), JP921.2 (B), JP1843.2 (B), U2.37 (Clk0), U10.6 (In05), U11.1 (Clk/In14)
/Clk2: J7.1, J8.5, U2.39 (Clk2), U6.14 (E), U7.25 (PHI2), U10.23 (In12), U11.23 (In12)
/D0: J8.9, LCD1.11 (DB0), U2.33 (D0), U4.13 (D0), U5.11 (D0), U6.15 (D7), U7.33 (D0), U8.9 (D7), U10.11 (In10)
/D1: J8.10, LCD1.12 (DB1), U2.32 (D1), U4.14 (D1), U5.12 (D1), U6.16 (D6), U7.32 (D1), U8.8 (D6), U10.10 (In09)
/D2: J8.11, LCD1.13 (DB2), U2.31 (D2), U4.15 (D2), U5.13 (D2), U6.17 (D5), U7.31 (D2), U8.7 (D5), U10.9 (In08)
/D3: J8.12, LCD1.14 (DB3), U2.30 (D3), U4.17 (D3), U5.15 (D3), U6.18 (D4), U7.30 (D3), U8.6 (D4), U10.8 (In07)
/D4: J8.13, LCD1.15 (DB4), U2.29 (D4), U4.18 (D4), U5.16 (D4), U6.19 (D3), U7.29 (D4), U8.5 (D3)
/D5: J8.14, LCD1.16 (DB5), U2.28 (D5), U4.19 (D5), U5.17 (D5), U6.20 (D2), U7.28 (D5), U8.4 (D2)
/D6: J8.15, LCD1.17 (DB6), U2.27 (D6), U4.20 (D6), U5.18 (D6), U6.21 (D1), U7.27 (D6), U8.3 (D1)
/D7: J8.16, LCD1.18 (DB7), U2.26 (D7), U4.21 (D7), U5.19 (D7), U6.22 (D0), U7.26 (D7), U8.2 (D0)
/DISP: J8.7, LCD1.7 (~CE), U11.21 (I/O/Q2)
/LD: J1.10, U8.11 (Load)
/Q0: J8.17, J9.1
/Q1: J8.18, J9.2
/Q2: J8.19, J9.3
/Q3: J8.20, J9.4
/Q4: J8.21, J9.5
/Q5: J8.22, J9.6
/RDY: J7.3, RP1.5 (R4), U2.2 (RDY)
/R~W: J8.6, U2.34 (R~W), U6.13 (R/~W), U7.22 (R/~W), U10.14 (In11), U11.14 (In11)
/SYNC: J7.6, U2.7 (SYNC)
/TMR: U3.23 (OUT), U11.2 (In01)
/~COM: U6.9 (~CS2), U11.20 (I/O/Q3)
/~IO: U10.20 (I/O/Q3), U11.13 (~OE/In13)
/~IRQ: J7.4, RP1.4 (R3), U2.4 (~IRQ), U6.7 (~IRQ), U7.21 (~IRQ), U11.18 (I/O/Q5)
/~KEY: J1.11, U8.1 (~OE), U11.22 (I/O/Q1)
/~NMI: J7.5, RP1.2 (R1), U2.6 (~NMI)
/~PORT: J5.12, J8.36, U11.17 (I/O/Q6)
/~RAM: U5.20 (~CE), U10.19 (I/O/Q4)
/~RD: J8.4, LCD1.6 (~RD), U4.24 (~OE), U5.22 (~OE), U11.15 (I/O/Q8)
/~ROM: U4.22 (~CE), U10.21 (I/O/Q2)
/~RST: J8.8, LCD1.10 (~RST), SW1.2, U2.40 (~RES), U7.34 (~RST), U9.1 (~RESET)
/~SO: RP1.3 (R2), U2.38 (~SO)
/~VIA: U7.23 (~CS2), U11.19 (I/O/Q4)
/~WR: J8.3, LCD1.5 (~WR), U5.27 (~WE), U11.16 (I/O/Q7)
GND: C1.2, C2.2, C3.2, C4.2, C5.2, C6.2, C7.2, C8.2, C9.2, C10.2, C11.2, C12.2, C13.2, J1.1, J2.1, J3.1, J4.1, J6.1, J7.2, J8.1, J8.23, LCD1.1 (FG), LCD1.2 (Vss), LCD1.22 (BLK), LCD1.25 (BLK), OSC1.4 (GND), OSC1.7 (GND), RV1.1, SW1.1, U1.6 (R0(1)), U1.7 (R0(2)), U1.10 (GND), U2.1 (Vss), U2.21 (Vss), U3.2 (LE), U3.3 (R1.J1), U3.4 (R2.J2), U3.5 (R4.J3), U3.7 (J16.H8), U3.9 (J14.H2), U3.12 (Vss), U3.15 (J12.T8), U3.16 (J11.T4), U3.19 (J08.U8), U3.22 (J05.U1), U4.16 (Vss), U5.14 (Vss), U6.1 (Vss), U7.1 (Vss), U8.10 (GND), U9.3 (GND), U10.12 (GND), U11.12 (GND)
unnamed: J1.2, U8.12 (Q7)
unnamed: J1.3, U8.13 (Q6)
unnamed: J1.4, U8.14 (Q5)
unnamed: J1.5, U8.15 (Q4)
unnamed: J1.6, U8.16 (Q3)
unnamed: J1.7, U8.17 (Q2)
unnamed: J1.8, U8.18 (Q1)
unnamed: J1.9, U8.19 (Q0)
unnamed: J2.2, U7.10 (PB0)
unnamed: J2.3, U7.11 (PB1)
unnamed: J2.4, U7.12 (PB2)
unnamed: J2.5, U7.13 (PB3)
unnamed: J2.6, U7.14 (PB4)
unnamed: J2.7, U7.15 (PB5)
unnamed: J2.8, U7.16 (PB6)
unnamed: J2.9, U7.17 (PB7)
unnamed: J2.10, U7.18 (CB1)
unnamed: J2.11, U7.19 (CB2)
unnamed: J3.2, U7.2 (PA0)
unnamed: J3.3, U7.3 (PA1)
unnamed: J3.4, U7.4 (PA2)
unnamed: J3.5, U7.5 (PA3)
unnamed: J3.6, U7.6 (PA4)
unnamed: J3.7, U7.7 (PA5)
unnamed: J3.8, U7.8 (PA6)
unnamed: J3.9, U7.9 (PA7)
unnamed: J3.10, U7.40 (CA1)
unnamed: J3.11, U7.39 (CA2)
unnamed: J4.2, U6.2 (Rx)
unnamed: J4.3, U6.6 (Tx)
unnamed: J4.4, U6.5 (~RTS)
unnamed: J4.5, U6.23 (~DCD)
unnamed: J4.6, U6.24 (~CTS)
unnamed: JP460.1 (A), U1.11 (Q1)
unnamed: JP921.1 (A), U1.1 (CP1..3), U1.12 (Q0)
unnamed: JP1843.1 (A), OSC1.8 (OUT), OSC1.11 (OUT), U1.14 (CP0)
unnamed: LCD1.4 (V0), RV1.2
unnamed: LCD1.20 (VOUT), RV1.3

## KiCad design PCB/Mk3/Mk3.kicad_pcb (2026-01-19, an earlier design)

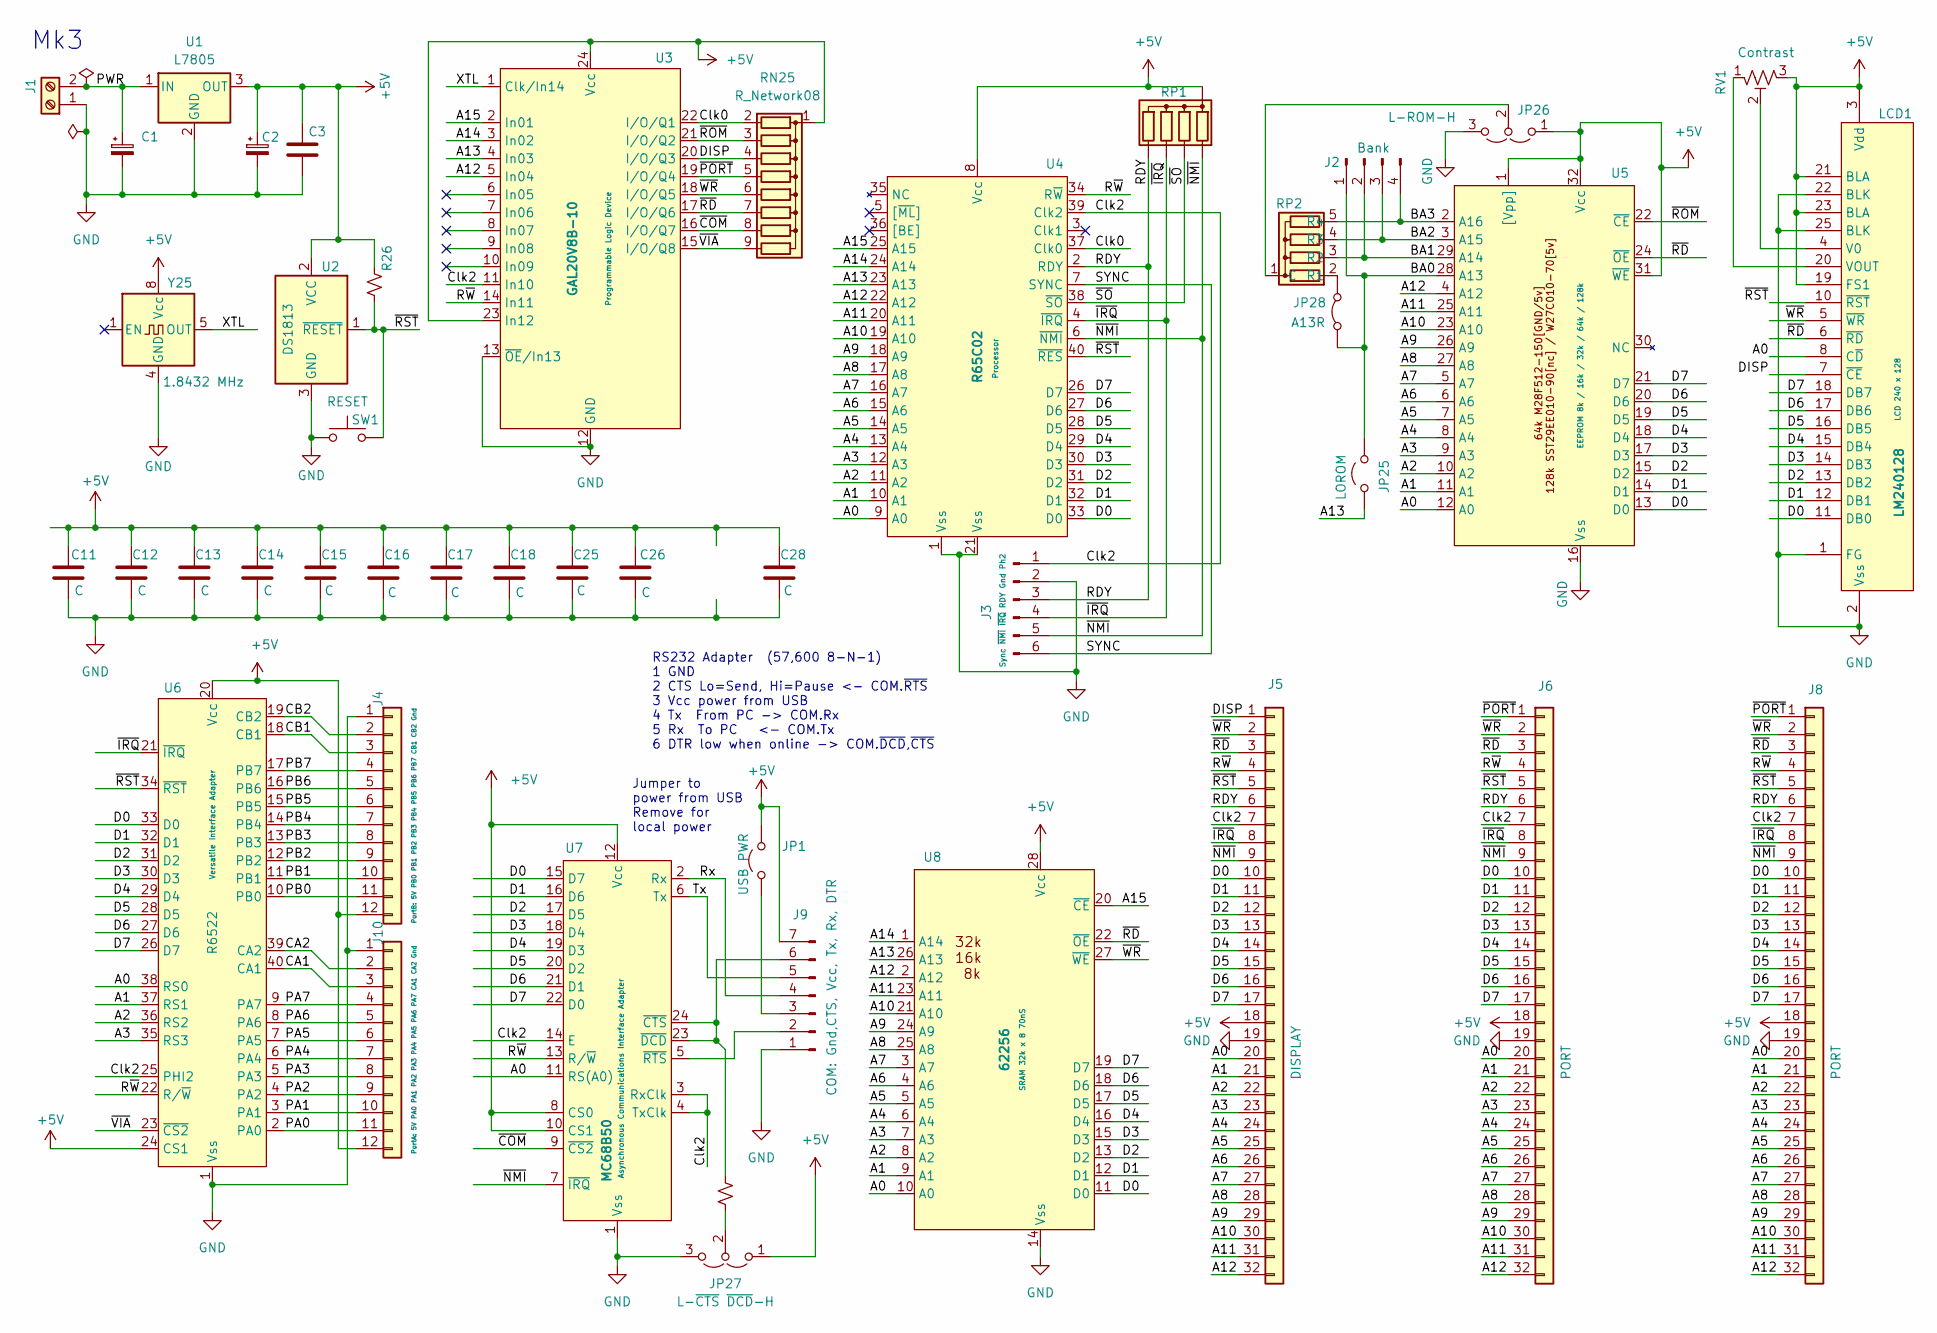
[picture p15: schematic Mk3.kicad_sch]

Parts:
C1, C2: C_Polarized_Small; CP_Radial_D10.0mm_P7.50mm
C3, C11, C12, C13, C14, C15, C16, C17, C18, C25, C26, C28: C; C_Disc_D7.5mm_W2.5mm_P5.00mm
J1: Power; TerminalBlock_MaiXu_MX126-5.0-02P_1x02_P5.00mm
J2: Bank; PinHeader_1x04_P2.54mm_Vertical
J3: Sync ~{NMI} ~{IRQ} RDY Gnd Ph2; PinHeader_1x06_P2.54mm_Vertical
J4: PortB: 5V PB0 PB1 PB2 PB3 PB4 PB5 PB6 PB7 CB1 CB2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; PinSocket_1x12_P2.54mm_Vertical
J5: DISPLAY; PinSocket_1x32_P2.54mm_Vertical
J6, J8: PORT; PinSocket_1x32_P2.54mm_Vertical
J9: COM: Gnd,CTS, Vcc, Tx, Rx, DTR; PinSocket_1x07_P2.54mm_Horizontal
J10: PortA: 5V PA0 PA1 PA2 PA3 PA4 PA5 PA6 PA7 CA1 CA2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; PinSocket_1x12_P2.54mm_Vertical
JP1: USB PWR; PinHeader_1x02_P2.54mm_Vertical
JP25: LOROM; PinHeader_1x02_P2.54mm_Vertical
JP26: L-ROM-H; PinHeader_1x03_P2.54mm_Vertical
JP27: L-~{CTS} ~{DCD}-H; PinHeader_1x03_P2.54mm_Vertical
JP28: A13R; SolderJumper-2_P1.3mm_Bridged_RoundedPad1.0x1.5mm
LCD1: LM240128; LCD 240x128
R25: PUp; R_Axial_DIN0204_L3.6mm_D1.6mm_P7.62mm_Horizontal
R26: R_Small_US; R_Axial_DIN0204_L3.6mm_D1.6mm_P7.62mm_Horizontal
RN25: R_Network08; R_Array_SIP9
RP1, RP2: R_Array_SIP5
RV1: Contrast; Potentiometer_Piher_PT-15-V15_Vertical
SW1: RESET; SW_PUSH_1P1T_6x3.5mm_H4.3_APEM_MJTP1243
U1: L7805; TO-220-3_Vertical
U2: DS1813; TO-92L_Wide
U3: GAL20V8B-10; DIP-24_W7.62mm_LongPads
U4: R65C02; DIP-40_W15.24mm_LongPads
U5: EEPROM; DIP-32_W15.24mm_LongPads
U6: R6522; DIP-40_W15.24mm_LongPads
U7: MC68B50; DIP-24_W15.24mm_LongPads
U8: 62256; DIP-28_W15.24mm_LongPads
Y25: 1.8432 MHz; Oscillator_DIP-8

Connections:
+5V: C2.1, C3.1, C11.1, C12.1, C13.1, C14.1, C15.1, C16.1, C17.1, C18.1, C25.1, C26.1, C28.1, J4.12, J5.18, J6.18, J8.18, J9.7, J10.12, JP1.2 (B), JP26.1 (A), JP27.1 (A), LCD1.3 (Vdd), LCD1.19 (FS1), LCD1.21 (BLA), LCD1.23 (BLA), R26.1, RN25.1 (common), RP1.1 (C), RV1.3, U1.3 (OUT), U2.2 (VCC), U3.23 (In12), U3.24 (Vcc), U4.8 (Vcc), U5.1 ([Vpp]), U5.31 (~WE), U5.32 (Vcc), U6.20 (Vcc), U6.24 (CS1), U7.8 (CS0), U7.10 (CS1), U7.12 (Vcc), U8.28 (Vcc), Y25.8 (Vcc)
/A0: J5.20, J6.20, J8.20, LCD1.8 (C~D), U4.9 (A0), U5.12 (A0), U6.38 (RS0), U7.11 (RS(A0)), U8.10 (A0)
/A1: J5.21, J6.21, J8.21, U4.10 (A1), U5.11 (A1), U6.37 (RS1), U8.9 (A1)
/A2: J5.22, J6.22, J8.22, U4.11 (A2), U5.10 (A2), U6.36 (RS2), U8.8 (A2)
/A3: J5.23, J6.23, J8.23, U4.12 (A3), U5.9 (A3), U6.35 (RS3), U8.7 (A3)
/A4: J5.24, J6.24, J8.24, U4.13 (A4), U5.8 (A4), U8.6 (A4)
/A5: J5.25, J6.25, J8.25, U4.14 (A5), U5.7 (A5), U8.5 (A5)
/A6: J5.26, J6.26, J8.26, U4.15 (A6), U5.6 (A6), U8.4 (A6)
/A7: J5.27, J6.27, J8.27, U4.16 (A7), U5.5 (A7), U8.3 (A7)
/A8: J5.28, J6.28, J8.28, U4.17 (A8), U5.27 (A8), U8.25 (A8)
/A9: J5.29, J6.29, J8.29, U4.18 (A9), U5.26 (A9), U8.24 (A9)
/A10: J5.30, J6.30, J8.30, U4.19 (A10), U5.23 (A10), U8.21 (A10)
/A11: J5.31, J6.31, J8.31, U4.20 (A11), U5.25 (A11), U8.23 (A11)
/A12: J5.32, J6.32, J8.32, U3.5 (In04), U4.22 (A12), U5.4 (A12), U8.2 (A12)
/A13: JP25.1 (A), U3.4 (In03), U4.23 (A13), U8.26 (A13)
/A14: U3.3 (In02), U4.24 (A14), U8.1 (A14)
/A15: U3.2 (In01), U4.25 (A15), U8.20 (~CE)
/BA0: J2.1, JP25.2 (B), JP28.1 (A), U5.28 (A13)
/BA1: J2.2, RP2.3 (R2), U5.29 (A14)
/BA2: J2.3, RP2.4 (R3), U5.3 (A15)
/BA3: J2.4, RP2.5 (R4), U5.2 (A16)
/CA1: J10.3, U6.40 (CA1)
/CA2: J10.2, U6.39 (CA2)
/CB1: J4.3, U6.18 (CB1)
/CB2: J4.2, U6.19 (CB2)
/Clk0: RN25.2 (R1), U3.22 (I/O/Q1), U4.37 (Clk0)
/Clk2: J3.1, J5.7, J6.7, J8.7, U3.11 (In10), U4.39 (Clk2), U6.25 (PHI2), U7.3 (RxClk), U7.4 (TxClk), U7.14 (E)
/D0: J5.10, J6.10, J8.10, LCD1.11 (DB0), U4.33 (D0), U5.13 (D0), U6.33 (D0), U7.15 (D7), U8.11 (D0)
/D1: J5.11, J6.11, J8.11, LCD1.12 (DB1), U4.32 (D1), U5.14 (D1), U6.32 (D1), U7.16 (D6), U8.12 (D1)
/D2: J5.12, J6.12, J8.12, LCD1.13 (DB2), U4.31 (D2), U5.15 (D2), U6.31 (D2), U7.17 (D5), U8.13 (D2)
/D3: J5.13, J6.13, J8.13, LCD1.14 (DB3), U4.30 (D3), U5.17 (D3), U6.30 (D3), U7.18 (D4), U8.15 (D3)
/D4: J5.14, J6.14, J8.14, LCD1.15 (DB4), U4.29 (D4), U5.18 (D4), U6.29 (D4), U7.19 (D3), U8.16 (D4)
/D5: J5.15, J6.15, J8.15, LCD1.16 (DB5), U4.28 (D5), U5.19 (D5), U6.28 (D5), U7.20 (D2), U8.17 (D5)
/D6: J5.16, J6.16, J8.16, LCD1.17 (DB6), U4.27 (D6), U5.20 (D6), U6.27 (D6), U7.21 (D1), U8.18 (D6)
/D7: J5.17, J6.17, J8.17, LCD1.18 (DB7), U4.26 (D7), U5.21 (D7), U6.26 (D7), U7.22 (D0), U8.19 (D7)
/DISP: J5.1, LCD1.7 (~CE), RN25.4 (R3), U3.20 (I/O/Q3)
/PA0: J10.11, U6.2 (PA0)
/PA1: J10.10, U6.3 (PA1)
/PA2: J10.9, U6.4 (PA2)
/PA3: J10.8, U6.5 (PA3)
/PA4: J10.7, U6.6 (PA4)
/PA5: J10.6, U6.7 (PA5)
/PA6: J10.5, U6.8 (PA6)
/PA7: J10.4, U6.9 (PA7)
/PB0: J4.11, U6.10 (PB0)
/PB1: J4.10, U6.11 (PB1)
/PB2: J4.9, U6.12 (PB2)
/PB3: J4.8, U6.13 (PB3)
/PB4: J4.7, U6.14 (PB4)
/PB5: J4.6, U6.15 (PB5)
/PB6: J4.5, U6.16 (PB6)
/PB7: J4.4, U6.17 (PB7)
/PWR: C1.1, J1.2, U1.1 (IN)
/RDY: J3.3, J5.6, J6.6, J8.6, RP1.5 (R4), U4.2 (RDY)
/Rx: J9.4, U7.2 (Rx)
/R~W: J5.4, J6.4, J8.4, U3.14 (In11), U4.34 (R~W), U6.22 (R/~W), U7.13 (R/~W)
/SYNC: J3.6, U4.7 (SYNC)
/Tx: J9.5, U7.6 (Tx)
/XTL: U3.1 (Clk/In14), Y25.5 (OUT)
/~COM: RN25.8 (R7), U3.16 (I/O/Q7), U7.9 (~CS2)
/~IRQ: J3.4, J5.8, J6.8, J8.8, RP1.4 (R3), U4.4 (~IRQ), U6.21 (~IRQ)
/~NMI: J3.5, J5.9, J6.9, J8.9, RP1.2 (R1), U4.6 (~NMI), U7.7 (~IRQ)
/~PORT: J6.1, J8.1, RN25.5 (R4), U3.19 (I/O/Q4)
/~RD: J5.3, J6.3, J8.3, LCD1.6 (~RD), RN25.7 (R6), U3.17 (I/O/Q6), U5.24 (~OE), U8.22 (~OE)
/~ROM: RN25.3 (R2), U3.21 (I/O/Q2), U5.22 (~CE)
/~RST: J5.5, J6.5, J8.5, LCD1.10 (~RST), R26.2, SW1.2, U2.1 (~RESET), U4.40 (~RES), U6.34 (~RST)
/~SO: RP1.3 (R2), U4.38 (~SO)
/~VIA: RN25.9 (R8), U3.15 (I/O/Q8), U6.23 (~CS2)
/~WR: J5.2, J6.2, J8.2, LCD1.5 (~WR), RN25.6 (R5), U3.18 (I/O/Q5), U8.27 (~WE)
GND: C1.2, C2.2, C3.2, C11.2, C12.2, C13.2, C14.2, C15.2, C16.2, C17.2, C18.2, C25.2, C26.2, C28.2, J1.1, J3.2, J4.1, J5.19, J6.19, J8.19, J9.1, J10.1, JP26.3 (B), JP27.3 (B), LCD1.1 (FG), LCD1.2 (Vss), LCD1.22 (BLK), LCD1.25 (BLK), SW1.1, U1.2 (GND), U2.3 (GND), U3.12 (GND), U3.13 (~OE/In13), U4.1 (Vss), U4.21 (Vss), U5.16 (Vss), U6.1 (Vss), U7.1 (Vss), U8.14 (Vss), Y25.4 (GND)
unnamed: J9.2, U7.5 (~RTS)
unnamed: J9.3, JP1.1 (A)
unnamed: J9.6, R25.2, U7.23 (~DCD), U7.24 (~CTS)
unnamed: JP26.2 (C), RP2.1 (C)
unnamed: JP27.2 (C), R25.1
unnamed: JP28.2 (B), RP2.2 (R1)
unnamed: LCD1.4 (V0), RV1.2
unnamed: LCD1.20 (VOUT), RV1.1

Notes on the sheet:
Mk3
RS232 Adapter (57,600 8-N-1) 1 GND 2 CTS Lo=Send, Hi=Pause <- COM.~{RTS} 3 Vcc power from USB 4 Tx From PC -> COM.Rx 5 Rx To PC <- COM.Tx 6 DTR low when online -> COM.~{DCD},~{CTS}
Jumper to power from USB Remove for local power

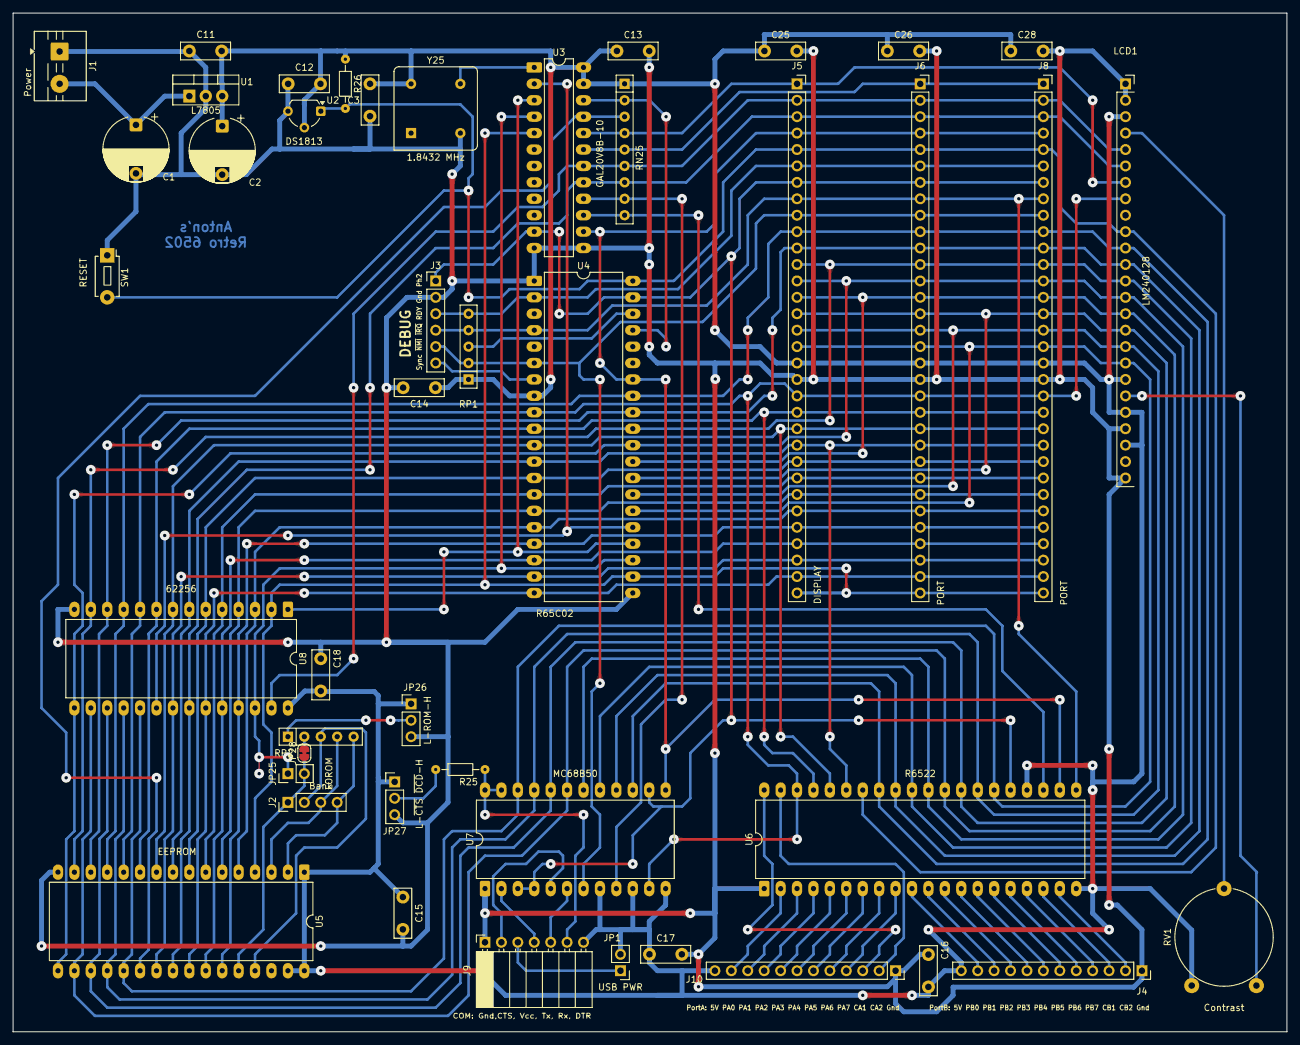
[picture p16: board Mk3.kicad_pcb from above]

Board: 2 copper layers, 197.0 x 157.5 mm, 45 parts (0 on the bottom side), 78 nets.

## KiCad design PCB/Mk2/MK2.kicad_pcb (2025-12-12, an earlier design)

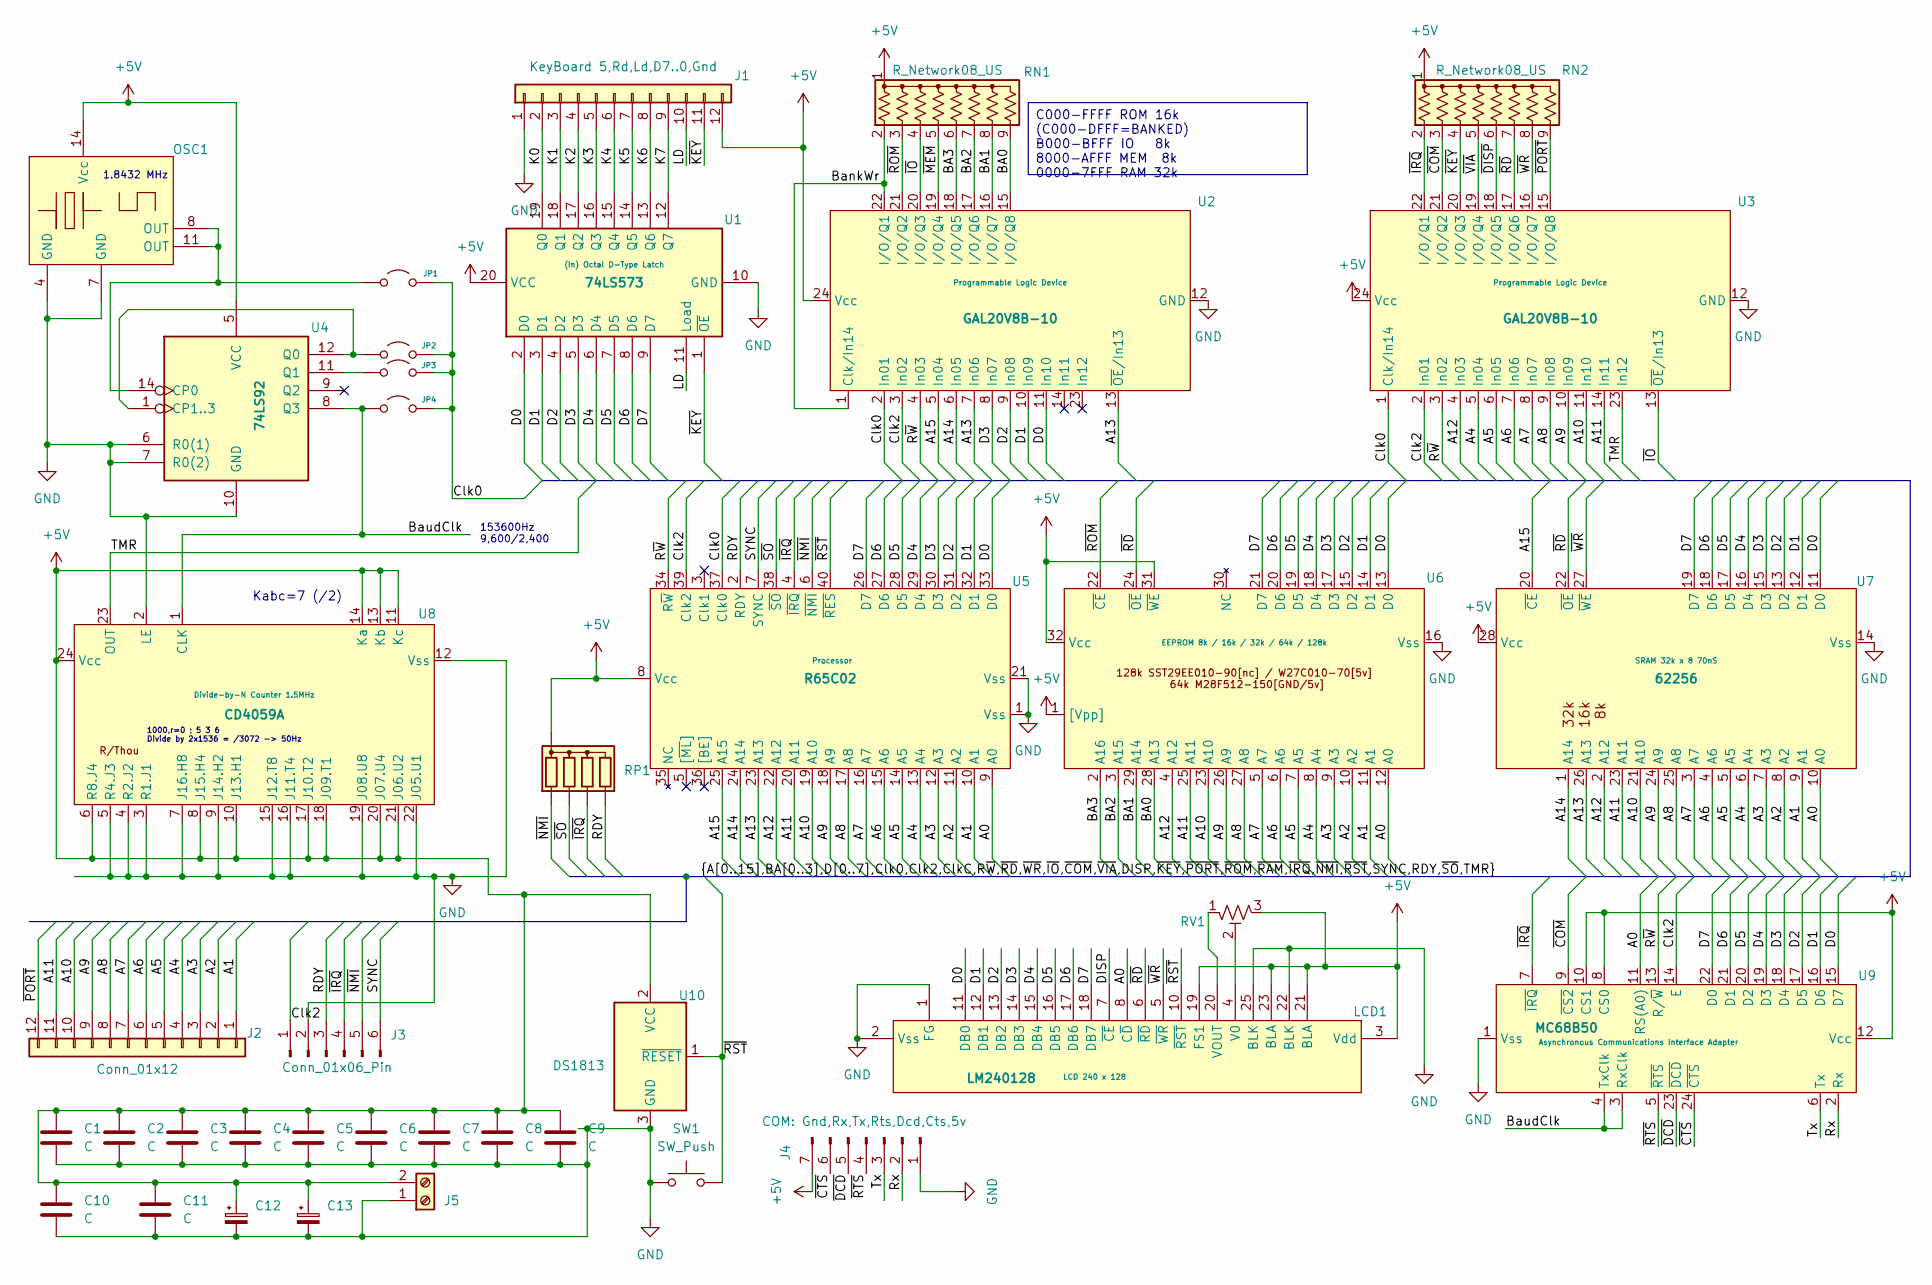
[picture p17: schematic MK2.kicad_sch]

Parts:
C1, C3, C4, C6, C7, C8, C9, C10: C; C_Disc_D7.5mm_W2.5mm_P5.00mm
C2, C5, C11: C; C_Rect_L11.0mm_W2.8mm_P10.00mm_MKT
C12, C13: C_Polarized_Small; CP_Radial_D10.0mm_P7.50mm
J1: KeyBoard 5,Rd,Ld,D7..0,Gnd; PinHeader_1x12_P2.54mm_Vertical
J2: Conn_01x12; PinSocket_1x12_P2.54mm_Vertical
J3: Conn_01x06_Pin; PinHeader_1x06_P2.54mm_Vertical
J4: COM: Gnd,Rx,Tx,Rts,Dcd,Cts,5v; PinSocket_1x07_P2.54mm_Horizontal
J5: Screw_Terminal_01x02; TerminalBlock_MaiXu_MX126-5.0-02P_1x02_P5.00mm
JP1, JP2, JP3, JP4: Jumper_2_Open; PinHeader_1x02_P2.54mm_Vertical
LCD1: LM240128; LCD 240x128
OSC1: DIP-14_W7.62mm_LongPads
RN1, RN2: R_Network08_US; R_Array_SIP9
RP1: R_Array_SIP5
RV1: R_Trim; Potentiometer_Runtron_RM-065_Vertical
SW1: SW_Push; MiniSwitch
U1: 74LS573; DIP-20_W7.62mm_LongPads
U2, U3: GAL20V8B-10; DIP-24_W7.62mm_LongPads
U4: 74LS92; DIP-14_W7.62mm
U5: R65C02; DIP-40_W15.24mm_LongPads
U6: EEPROM; DIP-32_W15.24mm_LongPads
U7: 62256; DIP-28_W15.24mm_LongPads
U8: CD4059A; DIP-24_W7.62mm_LongPads
U9: MC68B50; DIP-24_W15.24mm_LongPads
U10: DS1813; TO-92L_Inline

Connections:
+5V: C1.1, C2.1, C3.1, C4.1, C5.1, C6.1, C7.1, C8.1, C9.1, C10.1, C11.1, C12.1, C13.1, J1.12, J4.7, J5.2, LCD1.3 (Vdd), LCD1.19 (FS1), LCD1.21 (BLA), LCD1.23 (BLA), OSC1.14 (Vcc), RN1.1 (common), RN2.1 (common), RP1.1 (C), RV1.3, U1.20 (VCC), U2.24 (Vcc), U3.24 (Vcc), U4.5 (VCC), U5.8 (Vcc), U6.1 ([Vpp]), U6.31 (~WE), U6.32 (Vcc), U7.28 (Vcc), U8.6 (R8.J4), U8.8 (J15.H4), U8.10 (J13.H1), U8.11 (Kc), U8.13 (Kb), U8.14 (Ka), U8.17 (J10.T2), U8.18 (J09.T1), U8.20 (J07.U4), U8.21 (J06.U2), U8.24 (Vcc), U9.8 (CS0), U9.10 (CS1), U9.12 (Vcc), U10.2 (VCC)
/A0: LCD1.8 (C~D), U5.9 (A0), U6.12 (A0), U7.10 (A0), U9.11 (RS(A0))
/A1: J2.1, U5.10 (A1), U6.11 (A1), U7.9 (A1)
/A2: J2.2, U5.11 (A2), U6.10 (A2), U7.8 (A2)
/A3: J2.3, U5.12 (A3), U6.9 (A3), U7.7 (A3)
/A4: J2.4, U3.5 (In04), U5.13 (A4), U6.8 (A4), U7.6 (A4)
/A5: J2.5, U3.6 (In05), U5.14 (A5), U6.7 (A5), U7.5 (A5)
/A6: J2.6, U3.7 (In06), U5.15 (A6), U6.6 (A6), U7.4 (A6)
/A7: J2.7, U3.8 (In07), U5.16 (A7), U6.5 (A7), U7.3 (A7)
/A8: J2.8, U3.9 (In08), U5.17 (A8), U6.27 (A8), U7.25 (A8)
/A9: J2.9, U3.10 (In09), U5.18 (A9), U6.26 (A9), U7.24 (A9)
/A10: J2.10, U3.11 (In10), U5.19 (A10), U6.23 (A10), U7.21 (A10)
/A11: J2.11, U3.14 (In11), U5.20 (A11), U6.25 (A11), U7.23 (A11)
/A12: U3.4 (In03), U5.22 (A12), U6.4 (A12), U7.2 (A12)
/A13: U2.7 (In06), U2.13 (~OE/In13), U5.23 (A13), U7.26 (A13)
/A14: U2.6 (In05), U5.24 (A14), U7.1 (A14)
/A15: U2.5 (In04), U5.25 (A15), U7.20 (~CE)
/BA0: RN1.9 (R8), U2.15 (I/O/Q8), U6.28 (A13)
/BA1: RN1.8 (R7), U2.16 (I/O/Q7), U6.29 (A14)
/BA2: RN1.7 (R6), U2.17 (I/O/Q6), U6.3 (A15)
/BA3: RN1.6 (R5), U2.18 (I/O/Q5), U6.2 (A16)
/BankWr: RN1.2 (R1), U2.1 (Clk/In14), U2.22 (I/O/Q1)
/BaudClk: JP4.1 (A), U4.8 (Q3), U8.1 (CLK), U9.3 (RxClk), U9.4 (TxClk)
/Clk0: JP1.2 (B), JP2.2 (B), JP3.2 (B), JP4.2 (B), U2.2 (In01), U3.1 (Clk/In14), U5.37 (Clk0)
/Clk2: J3.1, U2.3 (In02), U3.2 (In01), U5.39 (Clk2), U9.14 (E)
/D0: LCD1.11 (DB0), U1.2 (D0), U2.11 (In10), U5.33 (D0), U6.13 (D0), U7.11 (D0), U9.15 (D7)
/D1: LCD1.12 (DB1), U1.3 (D1), U2.10 (In09), U5.32 (D1), U6.14 (D1), U7.12 (D1), U9.16 (D6)
/D2: LCD1.13 (DB2), U1.4 (D2), U2.9 (In08), U5.31 (D2), U6.15 (D2), U7.13 (D2), U9.17 (D5)
/D3: LCD1.14 (DB3), U1.5 (D3), U2.8 (In07), U5.30 (D3), U6.17 (D3), U7.15 (D3), U9.18 (D4)
/D4: LCD1.15 (DB4), U1.6 (D4), U5.29 (D4), U6.18 (D4), U7.16 (D4), U9.19 (D3)
/D5: LCD1.16 (DB5), U1.7 (D5), U5.28 (D5), U6.19 (D5), U7.17 (D5), U9.20 (D2)
/D6: LCD1.17 (DB6), U1.8 (D6), U5.27 (D6), U6.20 (D6), U7.18 (D6), U9.21 (D1)
/D7: LCD1.18 (DB7), U1.9 (D7), U5.26 (D7), U6.21 (D7), U7.19 (D7), U9.22 (D0)
/DISP: LCD1.7 (~CE)
/K0: J1.2, U1.19 (Q0)
/K1: J1.3, U1.18 (Q1)
/K2: J1.4, U1.17 (Q2)
/K3: J1.5, U1.16 (Q3)
/K4: J1.6, U1.15 (Q4)
/K5: J1.7, U1.14 (Q5)
/K6: J1.8, U1.13 (Q6)
/K7: J1.9, U1.12 (Q7)
/LD: J1.10, U1.11 (Load)
/RDY: J3.3, RP1.5 (R4), U5.2 (RDY)
/Rx: J4.2, U9.2 (Rx)
/R~W: U2.4 (In03), U3.3 (In02), U5.34 (R~W), U9.13 (R/~W)
/SYNC: J3.6, U5.7 (SYNC)
/TMR: U3.23 (In12), U8.23 (OUT)
/Tx: J4.3, U9.6 (Tx)
/~COM: RN2.3 (R2), U3.21 (I/O/Q2), U9.9 (~CS2)
/~CTS: J4.6, U9.24 (~CTS)
/~DCD: J4.5, U9.23 (~DCD)
/~DISP: RN2.6 (R5), U3.18 (I/O/Q5)
/~IO: RN1.4 (R3), U2.20 (I/O/Q3), U3.13 (~OE/In13)
/~IRQ: J3.4, RN2.2 (R1), RP1.4 (R3), U3.22 (I/O/Q1), U5.4 (~IRQ), U9.7 (~IRQ)
/~KEY: J1.11, RN2.4 (R3), U1.1 (~OE), U3.20 (I/O/Q3)
/~MEM: RN1.5 (R4), U2.19 (I/O/Q4)
/~NMI: J3.5, RP1.2 (R1), U5.6 (~NMI)
/~PORT: J2.12, RN2.9 (R8), U3.15 (I/O/Q8)
/~RD: LCD1.6 (~RD), RN2.7 (R6), U3.17 (I/O/Q6), U6.24 (~OE), U7.22 (~OE)
/~ROM: RN1.3 (R2), U2.21 (I/O/Q2), U6.22 (~CE)
/~RST: LCD1.10 (~RST), SW1.2, U5.40 (~RES), U10.1 (~RESET)
/~RTS: J4.4, U9.5 (~RTS)
/~SO: RP1.3 (R2), U5.38 (~SO)
/~VIA: RN2.5 (R4), U3.19 (I/O/Q4)
/~WR: LCD1.5 (~WR), RN2.8 (R7), U3.16 (I/O/Q7), U7.27 (~WE)
GND: C1.2, C2.2, C3.2, C4.2, C5.2, C6.2, C7.2, C8.2, C9.2, C10.2, C11.2, C12.2, C13.2, J1.1, J3.2, J4.1, J5.1, LCD1.1 (FG), LCD1.2 (Vss), LCD1.22 (BLK), LCD1.25 (BLK), OSC1.4 (GND), OSC1.7 (GND), SW1.1, U1.10 (GND), U2.12 (GND), U3.12 (GND), U4.6 (R0(1)), U4.7 (R0(2)), U4.10 (GND), U5.1 (Vss), U5.21 (Vss), U6.16 (Vss), U7.14 (Vss), U8.2 (LE), U8.3 (R1.J1), U8.4 (R2.J2), U8.5 (R4.J3), U8.7 (J16.H8), U8.9 (J14.H2), U8.12 (Vss), U8.15 (J12.T8), U8.16 (J11.T4), U8.19 (J08.U8), U8.22 (J05.U1), U9.1 (Vss), U10.3 (GND)
unnamed: JP1.1 (A), OSC1.8 (OUT), OSC1.11 (OUT), U4.14 (CP0)
unnamed: JP2.1 (A), U4.1 (CP1..3), U4.12 (Q0)
unnamed: JP3.1 (A), U4.11 (Q1)
unnamed: LCD1.4 (V0), RV1.2
unnamed: LCD1.20 (VOUT), RV1.1

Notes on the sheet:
Kabc=7 (/2)
1.8432 MHz
1000,r=0 ; 5 3 6 Divide by 2x1536 = /3072 -> 50Hz
153600Hz 9,600/2,400
C000-FFFF ROM 16k (C000-DFFF=BANKED) B000-BFFF IO 8k 8000-AFFF MEM 8k 0000-7FFF RAM 32k

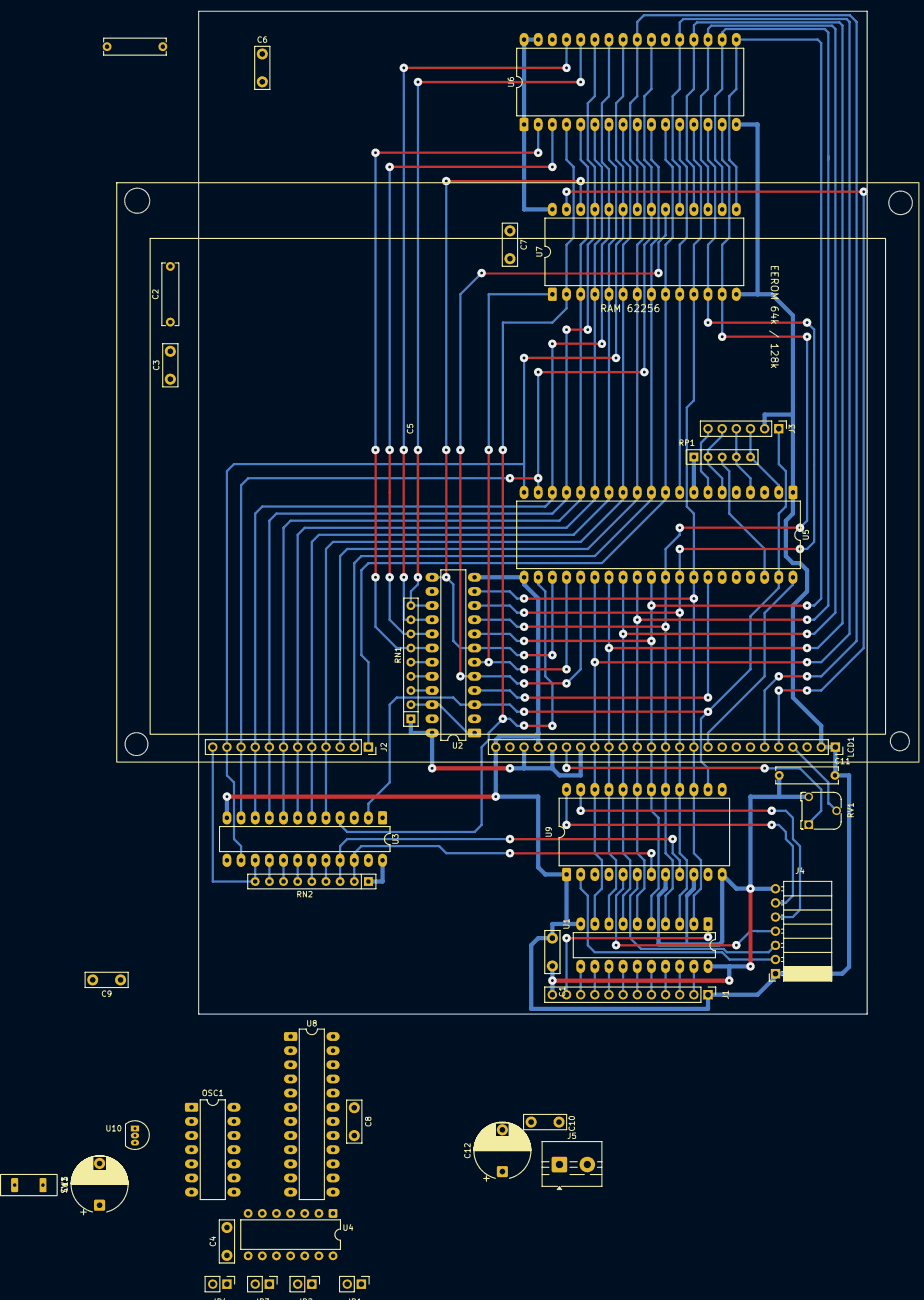
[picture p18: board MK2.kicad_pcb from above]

Board: 2 copper layers, 141.4 x 180.0 mm, 39 parts (0 on the bottom side), 71 nets.

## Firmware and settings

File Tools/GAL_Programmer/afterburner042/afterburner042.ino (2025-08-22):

                                                                      /*
                                       (banner font: aciiart.eu)
  _____________________________________________________________
 |       _    __ _            _                                \
 |      / \  / _| |_ ___  _ _| |__  _   _ _ __ ___  ___  _ _   |\
 |     / _ \| |_| '_/ _ \| '_/ '_ \| | | | '_/  _ \/ _ \| '_/  ||
 |    / ___ \  _| |_| __/| | | |_) | |_| | | | | | | __/| |    ||
 |   /_/   \_\|  \__\___||_| |____/\___,_|_| |_| |_|___||_|    ||
 \_____________________________________________________________||
   '------------------------------------------------------------'

   Afterburner: GAL IC Programmer for Arduino by -= olin =-

   Based on ATFblast 3.1 by Bruce Abbott
     http://www.bhabbott.net.nz/atfblast.html

   Based on GALBLAST by Manfred Winterhoff
     http://www.armory.com/%7Erstevew/Public/Pgmrs/GAL/_ClikMe1st.htm

   Based on GALmate by Yorck Thiele
     https://www.ythiee.com/2021/06/06/galmate-hardware/

   Supports:
   * National GAL16V8
   * Lattice GAL16V8A, GAL16V8B, GAL16V8D
   * Lattice GAL22V10B
   * Lattice GAL20V8
   * Atmel ATF16V8B, ATF16V8C, ATF22V10B, ATF22V10CQZ

   Requires:
   * afterburner PC program to upload JED fuse map, erase, read etc.
   * simple programming circuit. See: https://github.com/ole00/afterburner

                                                                       */


#define VERSION "0.4.2"

// was 57600
#define BAUD_RATE 38400

#define DEBUG_PES
#define DEBUG_VERIFY

//ARDUINO UNO pin mapping
//    GAL PIN NAME | ARDUINO UNO PIN NUMBER

//programing voltage control pin
#define PIN_VPP        11
#define PIN_SDOUT      12
#define PIN_STROBE     13
#define PIN_PV         9
#define PIN_SDIN       8

#define PIN_RA0         10
#define PIN_RA1         2
#define PIN_RA2         3
#define PIN_RA3         4
#define PIN_RA4         5
#define PIN_RA5         6
#define PIN_SCLK        7

#define COMMAND_NONE 0
#define COMMAND_UNKNOWN 1
#define COMMAND_IDENTIFY_PROGRAMMER '*'
#define COMMAND_HELP 'h'
#define COMMAND_UPLOAD 'u'
#define COMMAND_DEBUG 'd'
#define COMMAND_READ_PES 'p'
#define COMMAND_WRITE_PES 'P'
#define COMMAND_READ_FUSES 'r'
#define COMMAND_WRITE_FUSES 'w'
#define COMMAND_VERIFY_FUSES 'v'
#define COMMAND_ERASE_GAL 'c'
#define COMMAND_ERASE_GAL_ALL '~'
#define COMMAND_UTX '#'
#define COMMAND_ECHO 'e'
#define COMMAND_TEST_VOLTAGE 't'
#define COMMAND_SET_GAL_TYPE 'g'
#define COMMAND_ENABLE_CHECK_TYPE 'f'
#define COMMAND_DISABLE_CHECK_TYPE 'F'
#define COMMAND_ENABLE_SECURITY 's'
#define COMMAND_ENABLE_APD 'z'
#define COMMAND_DISABLE_APD 'Z'

#define READGAL 0
#define VERIFYGAL 1
#define READPES 2
#define SCLKTEST 3
#define WRITEGAL 4
#define ERASEGAL 5
#define ERASEALL 6
#define BURNSECURITY 7
#define WRITEPES 8
#define VPPTEST 9
#define INIT 100

//check GAL type before starting an operation
#define FLAG_BIT_TYPE_CHECK (1 << 0)

// ATF16V8C flavour
#define FLAG_BIT_ATF16V8C (1 << 1)

// Keep the power-down feature enabled for ATF C GALs
#define FLAG_BIT_APD (1 << 2)

// contents of pes[3]
// Atmel PES is text string eg. 1B8V61F1 or 3Z01V22F1
//                                 ^           ^
#define LATTICE 0xA1
#define NATIONAL 0x8F
#define SGSTHOMSON 0x20
#define ATMEL16 'V'
#define ATMEL22 '1'

typedef enum {
  UNKNOWN,
  GAL16V8,
  GAL20V8,
  GAL22V10,
  ATF16V8B,
  ATF22V10B,
  ATF22V10C,
  LAST_GAL_TYPE //dummy
} GALTYPE;

#define BIT_NONE 0
#define BIT_ZERO 1
#define BIT_ONE  2

// config bit numbers

#define CFG_BASE_16 2048
#define CFG_BASE_20 2560
#define CFG_BASE_22 5808

#define CFG_STROBE_ROW 0
#define CFG_SET_ROW 1

// Atmel power-down row
#define CFG_ROW_APD 59

// common CFG fuse address map for cfg16V8 and cfg20V8
// the only difference is the starting address: 2048 for cfg16V8 and 2560 for cfg20V8
// total size: 82
static const unsigned char cfgV8[]=
{
      80,81,82,83,84,85,86,87,88,89,90,91,92,93,94,95,96,97,98,99,100,101,102,103,104,105,106,107,108,109,110,111,
      0,1,2,3,
      145,
      72,73,74,75,76,77,78,79,
      144,
      4,5,6,7,
      112,113,114,115,116,117,118,119,120,121,122,123,124,125,126,127,128,129,130,131,132,133,134,135,136,137,138,139,140,141,142,143,
};

// common CFG fuse address map for cfg16V8AB and cfg20V8AB
// the only difference is the starting address: 2048 for cfg16V8AB and 2560 for cfg20V8AB
// total size: 82
static const unsigned char cfgV8AB[]=
{
      0,1,2,3,
      145,
      72,73,74,75,
      80,81,82,83,84,85,86,87,88,89,90,91,92,93,94,95,96,97,98,99,100,101,102,103,104,105,106,107,108,109,110,111,112,113,114,115,116,117,118,119,120,121,122,123,124,125,126,127,128,129,130,131,132,133,134,135,136,137,138,139,140,141,142,143,
      76,77,78,79,
      144,
      4,5,6,7,
};

// common CFG fuse address map for cfg22V10
// starting address: 5808
// total size 20
static const unsigned char cfgV10[]=
{
      1,0,3,2,5,4,7,6,9,8,11,10,13,12,15,14,17,16,19,18,
};


//   UES     user electronic signature
//   PES     programmer electronic signature (ATF = text string, others = Vendor/Vpp/timing)
//   cfg     configuration bits for OLMCs

// GAL info
static struct
{
    GALTYPE type;
    unsigned char id0,id1;          /* variant 1, variant 2 (eg. 16V8=0x00, 16V8A+=0x1A)*/
    short fuses;                    /* total number of fuses              */
    char pins;                      /* number of pins on chip             */
    char rows;                      /* number of fuse rows                */
    unsigned char bits;             /* number of fuses per row            */
    char uesrow;                    /* UES row number                     */
    short uesfuse;                  /* first UES fuse number              */
    char uesbytes;                  /* number of UES bytes                */
    char eraserow;                  /* row adddeess for erase             */
    char eraseallrow;               /* row address for erase all (also PES) */
    char pesrow;                    /* row address for PES read/write     */
    char pesbytes;                  /* number of PES bytes                */
    char cfgrow;                    /* row address of config bits (ACW)   */
    unsigned short cfgbase;         /* base address of the config bit numbers */
    const unsigned char *cfg;       /* pointer to config bit numbers      */
    unsigned char cfgbits;          /* number of config bits              */
    unsigned char cfgmethod;        /* strobe or set row for reading config */
}
galinfo[]=
{
//                           + fuses         + bits       +uesbytes   +pesrow          +cfgbase
//                           |     +pins     |  +uesrow   |  +eraserow|   +pesbytes    |        +cfg
//   +-- type   + id0 + id1  |     |   +rows |  |   +uesfuse |   +eraseallrow +cfgrow  |        |       + cfgbits        +cfgmethod
//   |          |     |      |     |   |     |  |   |     |  |   |    |   |   |        |        |       |                |
    {UNKNOWN,   0x00, 0x00,     0,  0,  0,   0,  0,    0, 0,  0,  0,  0,  8,  0,       0,        NULL,      0         , 0},
    {GAL16V8,   0x00, 0x1A,  2194, 20, 32,  64, 32, 2056, 8, 63, 62, 58,  8, 60, CFG_BASE_16, cfgV8AB, sizeof(cfgV8AB), CFG_STROBE_ROW},
    {GAL20V8,   0x20, 0x3A,  2706, 24, 40,  64, 40, 2568, 8, 63, 62, 58,  8, 60, CFG_BASE_20, cfgV8AB, sizeof(cfgV8AB), CFG_STROBE_ROW},
    {GAL22V10,  0x48, 0x49,  5892, 24, 44, 132, 44, 5828, 8, 61, 62, 58, 10, 16, CFG_BASE_22, cfgV10,  sizeof(cfgV10) , CFG_SET_ROW   },
    {ATF16V8B,  0x00, 0x00,  2194, 20, 32,  64, 32, 2056, 8, 63, 62, 58,  8, 60, CFG_BASE_16, cfgV8AB, sizeof(cfgV8AB), CFG_STROBE_ROW},
    {ATF22V10B, 0x00, 0x00,  5892, 24, 44, 132, 44, 5828, 8, 61, 62, 58, 10, 16, CFG_BASE_22, cfgV10,  sizeof(cfgV10) , CFG_SET_ROW   },
    {ATF22V10C, 0x00, 0x00,  5892, 24, 44, 132, 44, 5828, 8, 61, 62, 58, 10, 16, CFG_BASE_22, cfgV10,  sizeof(cfgV10) , CFG_SET_ROW   },
};

// MAXFUSES calculated as the biggest required space to hold the fuse bitmap + UES bitmap + CFG bitmap
// MAXFUSES = ((132 * 44 bits) / 8)  + uesbytes + ((20 + 1) / 8)      // +1 is the power-down extra fuse
//               726 + 8 + 3
#define MAXFUSES 737


GALTYPE gal __attribute__ ((section (".noinit"))); //the gal device index pointing to galinfo, value is preserved between resets

static short security = 0, erasetime = 100, progtime = 100, vpp = 0;

char echoEnabled;
unsigned char pes[12];
char line[64];
short lineIndex;
char endOfLine;
char mapUploaded;
char isUploading;
char uploadError;
unsigned char fusemap[MAXFUSES];
unsigned char flagBits;


static void setFuseBit(unsigned short bitPos);
static unsigned short checkSum(unsigned short n);
static char checkGalTypeViaPes(void);
static void turnOff(void);
static void printFormatedNumberHex2(unsigned char num) ;

// print some help on the serial console
void printHelp(char full) {
  Serial.println(F("AFTerburner v." VERSION));
  if (!full) {
    Serial.println(F("type 'h' for help"));
    return;
  }
  Serial.println(F("commands:"));
  Serial.println(F("  h - print help"));
  Serial.println(F("  e - toggle echo"));
  Serial.println(F("  p - read & print PES"));
  Serial.println(F("  r - read & print fuses"));
  Serial.println(F("  u - clear map and start upload of fuses into map (via #... lines)"));
  Serial.println(F("  w - write uploaded fuses (from map to chip)"));
  Serial.println(F("  v - verify fuses"));
  Serial.println(F("  c - erase chip"));
  Serial.println(F("  ~ - erase all (resets PES)"));
  Serial.println(F("  t - test VPP"));
}

static void setFlagBit(uint8_t flag, uint8_t value) {
    if (value) {
        flagBits |= flag;
    } else {
        flagBits &= ~flag;
    }
}


static void setupGpios(uint8_t pm) {

  // Serial input of the GAL chip, output from Arduino
  pinMode(PIN_SDIN, pm);

  pinMode(PIN_STROBE, pm);
  pinMode(PIN_PV, pm);
  pinMode(PIN_RA0, pm);
  pinMode(PIN_RA1, pm);
  pinMode(PIN_RA2, pm);
  pinMode(PIN_RA3, pm);
  pinMode(PIN_RA4, pm);
  pinMode(PIN_RA5, pm);
  pinMode(PIN_SCLK, pm);

  pinMode(PIN_VPP, pm);
}

// setup the Arduino board
void setup() {
// initialize serial:
  Serial.begin(BAUD_RATE,SERIAL_8N1);
  isUploading = 0;
  endOfLine = 0;
  echoEnabled = 0;
  mapUploaded = 0;
  lineIndex = 0;
  setFlagBit(FLAG_BIT_TYPE_CHECK, 1); //do type check

  // Serial output from the GAL chip, input for Arduino
  pinMode(PIN_SDOUT, INPUT);

  // Set all GPIO pins to Input to prevent accidents when
  // inserting the GAL IC into socket.
  setupGpios(INPUT);

  printHelp(0);
  Serial.println(">");
}


// read from serial line and discard the data
void readGarbage() {
  while (Serial.available() > 0) {
    Serial.read();
  }
}

// Reads input from the serial terminal and returns the command
// which is the first character of the entered text.

char handleTerminalCommands() {
  char c;

  while (Serial.available() > 0) {
    c = Serial.read();
    line[lineIndex] = c;
    if (c == '\n' || c == '\r') {
      endOfLine = 1;
    }
    //echo input to output
    else {
      if (!isUploading && echoEnabled) {
        Serial.print(c);
      }
    }
    if (lineIndex >= 62) {
      lineIndex = 0;
      readGarbage();
      Serial.println();
      Serial.println("Error: line too long.");
    } else {
      lineIndex++;
    }
  }
  if (endOfLine) {
    c = COMMAND_NONE;

    //single letter command entered
    if (lineIndex == 2) {
      c = line[0];
    } else if (lineIndex  > 2) {
      c = line[0];
      if (!isUploading || c != '#') {
        if (c != COMMAND_SET_GAL_TYPE) { // 'g'
          c = COMMAND_UNKNOWN;
        }
      }
    }
    if (!isUploading) {
      Serial.println();
      line[lineIndex] = 0;
      lineIndex = 0;
    }
    endOfLine = 0;
    return c;
  }
  return COMMAND_NONE;
}

// Parses decimal integer number typed as 4 digit.
// Returns the number value.
unsigned short parse4dec(char i) {
  unsigned short v = (line[i++] - '0') * 1000;
  v += (line[i++] - '0') * 100;
  v += (line[i++] - '0') * 10;
  v += line[i] - '0';
  return v;
}

// Converts textual hex value 0-9, A-F to a number.
unsigned char toHex(char c) {
  if (c >= '0' && c <= '9') return c - '0';
  if (c >= 'A' && c <= 'F') return c - 'A' + 10;
  if (c >= 'a' && c <= 'f') return c - 'a' + 10;
  return 0;
}

// Parses hexdecimal integer number typed as 2 digit.
// Returns the number value.
unsigned short parse2hex(char i) {
  if (line[i] == '\r' || line[i] ==  0 || line[i] == ' ') {
    return -1;
  }

  unsigned short v = toHex(line[i++]) << 4;
  return v + toHex(line[i]);
}

// Parses hexdecimal integer number typed as 4 digit.
// Returns the number value.
unsigned short parse4hex(char i) {
  if (line[i] == '\r' || line[i] ==  0 || line[i] == ' ') {
    return -1;
  }

  unsigned short v = ((unsigned short)toHex(line[i++])) << 12;
  v |= ((unsigned short)toHex(line[i++])) << 8;
  v |= toHex(line[i++]) << 4;
  return v + toHex(line[i]);
}

// Parses a line fed by the serial connection.
// This hnadles a primitive upload protocol that
// expects a programatic data feed - not suitable
// for human interaction.
// Data: each command on its own line
// line starts with '#' character followed by a command
// and a space. Then a command specific data follow.
// Commands:
// t <gal index>: gal type index to the GALTYPEE enum         - '#t2'
// f <fuse index> <row>: row of fuse-map data starting on fuse bit index
// c <checksum> : checksum of the whole fuse map
// e : end ofthe upload transfer - returns to terminal

void parseUploadLine() {
  switch (line[1]) {
    case 'e': {
      if (uploadError) {
        Serial.print(F("ER upload failed"));
      } else {
        Serial.print(F("OK upload finished"));
      }
      isUploading = 0;
    } break;

    // gal type
    case 't': {
      short v = line[3] - '0';
      if (v > 0 && v < LAST_GAL_TYPE) {
        gal = (GALTYPE) v;
        Serial.print(F("OK gal set: "));
        Serial.println((short) gal, DEC);
      } else {
        Serial.println(F("ER unknown gal index"));
        uploadError = 1;
      }
    } break;

    //fusemap data - #f aaaa ffff..
    // aaaa = 4 decimal digit address
    // ff ... fuse flags as hex
    case 'f': {
      char i = 8;
      char j;
      unsigned short addr = parse4dec(3);
      short v;
      do {
        v = parse2hex(i);
        if (v >= 0) {
          for (j = 0; j < 8; j++) {
            // if fuse bit is set -> then change the fusemap
            if (v & (1 << j)) {
              setFuseBit(addr);
            }
            addr++;
          }
          i += 2;
        }
      } while (v >= 0);

      //any fuse being set is considered as uploaded fuse map
      mapUploaded = 1;

      Serial.print(F("OK "));
      Serial.println((short) addr, DEC);
    } break;

    //checksum
    case 'c': {
      unsigned short val = parse4hex(3);
      unsigned char apdFuse = (flagBits & FLAG_BIT_APD) ? 1 : 0;
      unsigned short cs = checkSum(galinfo[gal].fuses + apdFuse);
      if (cs == val) {
        Serial.println(F("OK checksum matches"));
      } else {
        uploadError = 1;
        Serial.print(F("ER checksum:"));
        Serial.print(cs, HEX);
        Serial.print(F(" expected:"));
        Serial.println(val, HEX);
      }
    } break;

    // PES
    case 'p': {
      uint8_t i = 0;
      uint8_t j = 3;
      while (i < 8) {
        pes[i] = parse2hex(j);
        i++;
        j+=3; //AB:00:...  - 3 characters per one PES byte
      }
    } break;

    default:
      uploadError = 1;
      Serial.println(F("ER unknown upload cmd"));
  }

  lineIndex = 0;
}
// *********************************************************


// set/reset individual pins of GAL
static void setVCC(char on) {
    //no control for turning the voltage on of
    //it is assumed the voltage is always on
}

static void setVPP(char on) {
  //programming voltage is controlled by VPP_PIN,
  //but the programming voltage must be set manually by user turning a Pot
  digitalWrite(PIN_VPP, on ? 1 : 0);

  //Serial.print(F("VPP set to:"));
  //Serial.println( on ? "12V": "5V");
  delay(10);
}



static void setSTB(char on) {
   digitalWrite(PIN_STROBE, on ? 1:0);
}

static void setPV(char on) {
   digitalWrite(PIN_PV, on ? 1:0);
}

static void setSDIN(char on) {
  digitalWrite(PIN_SDIN, on ? 1:0);
}

static void setSCLK(char on){
   digitalWrite(PIN_SCLK, on ? 1:0);
}

// output row address (RA0-5)
static void setRow(char row)
{
  digitalWrite(PIN_RA0, (row & 0x1));
  digitalWrite(PIN_RA1, ((row & 0x2) ? 1:0));
  digitalWrite(PIN_RA2, ((row & 0x4) ? 1:0));
  digitalWrite(PIN_RA3, ((row & 0x8) ? 1:0));
  digitalWrite(PIN_RA4, ((row & 0x10) ? 1:0));
  digitalWrite(PIN_RA5, ((row & 0x20) ? 1:0));
}

// serial data out form the GAL chip -> received by Arduino
static char getSDOUT(void)
{
  return digitalRead(PIN_SDOUT) != 0;
}

// GAL finish sequence
static void turnOff(void)
{
    delay(100);
    setPV(0);    // P/V- low
    setRow(0x3F);// RA0-5 high
    setSDIN(1);  // SDIN high
    setVPP(0);   // Vpp off (+12V)
    setPV(1);    // P/V- high
    delay(2);
    setVCC(0);   // turn off VCC (if controlled)

    setupGpios(INPUT);
    delay(100); //ensure VPP is low
}

// GAL init sequence
static void turnOn(char mode) {
    setupGpios(OUTPUT);

    if (
      mode == WRITEGAL ||
      mode == ERASEGAL ||
      mode == ERASEALL ||
      mode == BURNSECURITY ||
      mode == WRITEPES ||
      mode == VPPTEST ||
      mode == READPES ||
      mode == READGAL
    ) {
        mode = 1;
    } else {
        mode = 0;
    }
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
void loop() {


    // read a command from serial terminal or COMMAND_NONE if nothing is received from serial
    char command = handleTerminalCommands();

    // any unexpected input when uploading fuse map terminates the upload process
    if (isUploading && command != COMMAND_UTX && command != COMMAND_NONE) {
      Serial.println(F("ER upload aborted"));
      isUploading = 0;
      lineIndex = 0;
    }

    // handle commands received from the serial terminal
    switch (command) {

      // print some help
      case COMMAND_HELP: {  // 'h'
        printHelp(1);
      } break;

      case COMMAND_IDENTIFY_PROGRAMMER : { // '*'
        printHelp(0);
      } break;

      // verify fuse-map bits and bits read from the GAL chip
      case COMMAND_VERIFY_FUSES: { // 'v'
        if (mapUploaded) {
          if (doTypeCheck()) {
            readOrVerifyGal(1); //just verify, do not overwrite fusemap
          }
        } else {
          printNoFusesError();
        }
      } break;

      // handle upload command - start the download of fuse-map
      case COMMAND_UPLOAD: { // 'u'
        short i;
        // clean fuses
        for (i = 0; i < MAXFUSES; i++) {
          fusemap[i] = 0;
        }
        isUploading = 1;
        uploadError = 0;
      } break;

      // command of the upload protocol
      case COMMAND_UTX : { // '#' upload rows
        parseUploadLine();
      } break;

      // read and print the PES
      case COMMAND_READ_PES : { // 'p'
        char type;
        readPes();
        type = checkGalTypeViaPes();
        parsePes(type);
        printPes(type);
      } break;

      case COMMAND_WRITE_PES : { // 'P'
        char type;
        type = checkGalTypeViaPes();
        parsePes(type);
        writePes();
      } break;

      // read fuse-map from the GAL and print it in the JEDEC form
      case COMMAND_READ_FUSES : { // 'r'
        if (doTypeCheck()) {
          readOrVerifyGal(0); //just read, no verification
          printJedec();
        }
      } break;

      // write current fuse-map to the GAL chip
      case COMMAND_WRITE_FUSES : { // 'w'
        if (mapUploaded) {
          if (doTypeCheck()) {
            writeGal();
            //TODO security
          }
        } else {
          printNoFusesError();
        }
      } break;

      // erases the fuse-map on the GAL chip
      case COMMAND_ERASE_GAL: { // 'c'
        if (doTypeCheck()) {
          eraseGAL(0);
        }
      } break;
      // erases PES and the fuse-map on the GAL chip
      case COMMAND_ERASE_GAL_ALL: {  // '~'
        if (doTypeCheck()) {
          eraseGAL(1);
        }
      } break;

      // sets the security bit
      case COMMAND_ENABLE_SECURITY: { // 's'
        if (doTypeCheck()) {
          secureGAL();
        }
      } break;

      // keep atmel power-down feature enabled during write
      case COMMAND_ENABLE_APD: { // 'z'
        setFlagBit(FLAG_BIT_APD, 1);
        Serial.println(F("OK APD set"));
      } break;

      case COMMAND_DISABLE_APD: { // 'Z'
        setFlagBit(FLAG_BIT_APD, 0);
        Serial.println(F("OK APD cleared"));
      } break;

      // toggles terminal echo
      case COMMAND_ECHO : { // 'e'
        echoEnabled = 1 - echoEnabled;
      } break;

      case COMMAND_TEST_VOLTAGE : { // 't'
        testVoltage(20);
      } break;

      case COMMAND_SET_GAL_TYPE : { // 'g'
        char type = line[1] - '0';
        if (type >= 1 && type < LAST_GAL_TYPE) {
          gal = (GALTYPE) type;
          if (0 == flagBits & FLAG_BIT_TYPE_CHECK) { //no type check requested
            setGalDefaults();
          }
        } else {
          Serial.println(F("ER Unknown gal type"));
        }
      } break;
      case COMMAND_ENABLE_CHECK_TYPE: { // 'f'
        setFlagBit(FLAG_BIT_TYPE_CHECK, 1);
      } break;
      case COMMAND_DISABLE_CHECK_TYPE: { // 'F'
        setFlagBit(FLAG_BIT_TYPE_CHECK, 0);
      } break;
      default: {
        if (command != COMMAND_NONE) { // null
          Serial.print(F("ER Unknown command: "));
          Serial.println(line);
        }
      }
    }

    // display prompt character - important for the PC program to check that Arduino
    // finished the desired operation
    if (command != COMMAND_NONE) { // null
      Serial.println(F(">"));
    }

    // and that's it!
}

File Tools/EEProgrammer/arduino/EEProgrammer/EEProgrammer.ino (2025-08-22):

/*
Simple DIY EEPROM programer for PQ 52B33 8k x 8 EEPROM (Using Arduino Nano)

The 52B33 supports a chip-erase that clears the whole chip in one step. In this event it is not necessary to write FF
to a location before writing data to it.

In this programmer, 'E'rase clears the chip and enables 'fast' writes (skips writting the FF).
As soon as anything other than a write command (either intel hex line or 'W'rite) is used, fast mode is disabled.

Circuit uses 74hc164 shift regisisters connected in series to make a 16 bit shift register which provides the address lines.
(Most significat bit is shifted out first.) Two pins are used to drive this - SHIFT_DATA & SHIFT_CLK

A number of i/o pins are used to connect to the data lines of the eeprom.

This programmer is based on request/response protocol, line by line. (CR is ignored) LF marks end of line.

Java program EEPromProgrammer (with jSerialComm-2.9.2.jar) acts as host on PC side.

Anton Schoultz 2023

?       Help
E       Erase the chip (enables fast write)
R[nn]   Read [nn] rows of data
Wxxxx   Write hex data at current address and move on
Ahhll   Set current address as hhll
:xx..   Intel Hex8 format line (type 00=data record)
Dxxxx[A] Dump as intel hex data records. xxxx=size, A=Ack

*/

/* sets the comunication baud rate - must match the PC program */
// 9600,19200,31250,38400,57600,74880,115200
#define SERIAL_BAUD_RATE 115200

// 8K=$2000 (8192)
#define EEPROM_SIZE 0x2000
/*
Some delay constants
*/
#define DLY_ERASE 20  // spec is 10 mSec
#define DLY_WRITE 15  // spec says 9 mSec
#define DLY_WAIT 1
#define DLY_MODE 2

/* 
Pins used to drive the shift registers 
for the address lines 
*/
#define SHIFT_DATA 2
#define SHIFT_CLK 3
/*
Pins used to connect directly to the ee data pins
*/
#define EE_D0 4
#define EE_D1 5
#define EE_D2 6
#define EE_D3 7
#define EE_D4 8
#define EE_D5 9
#define EE_D6 10
#define EE_D7 11
#define EE_nOE 12
#define EE_nWE 13
#define EE_nCC A0


/*
Programmer mode 
*/
#define MODE_NONE -1
#define MODE_READ 0
#define MODE_WRITE 1

/* no of bytes to write into iHEX record */
#define PG 32

#define CR 13
#define LF 10

int addr = 0;    // current address
int sum = 0;     // check sum while reading/writing iHEX
int maxAdr = 0;  // tracks last address written (default end for 'D'ump)

int mode = MODE_NONE;  // current mode

// controls if we erase each location first or not
// (it is not necessary if the chip has been erased)
// 'E'rase truns this on, any non-write command turns it off
boolean fastWrite = false;

/* buffers are shared between subroutines */
char strBuf[80];  // string buffer

// input
String input;  // input string
int ix;        // index into input

byte dataBuf[40];  // data buffer

/* --------------------------------------------- setup
Sets up the pin modes and safe state for control
lines. Display help and stat off in READ mode.
*/
void setup() {
  // pins that drive the address shift registers
  pinMode(SHIFT_DATA, OUTPUT);
  pinMode(SHIFT_CLK, OUTPUT);
  // output enable (!RD)
  digitalWrite(EE_nOE, 1);
  pinMode(EE_nOE, OUTPUT);
  // write enable (!WR)
  digitalWrite(EE_nWE, 1);
  pinMode(EE_nWE, OUTPUT);
  // chip clear / erase chip (!CC)
  digitalWrite(EE_nCC, 1);
  pinMode(EE_nCC, OUTPUT);
  // start up serial port
  Serial.begin(SERIAL_BAUD_RATE);
  Serial.println(F("EEProgrammer - Anton Schoultz - Jan 2025"));
  Serial.println(F("========================================"));
  // greeting
  help();
  // initial mode
  mode = MODE_NONE;
  readyToRead();
}

/* --------------------------------------------- help 
Dispalys the help screen 
*/
void help() {
  Serial.println(F("EEPROM programer - by Anton Schoultz 2024/11/15"));
  Serial.println(F("?       Help"));
  Serial.println(F("E       Erase the chip (enables fast write)"));
  Serial.println(F("V       Verify that chip is errased.(All FF)"));
  Serial.println(F("R[nn]   Read [nn] rows of data"));
  Serial.println(F("Wxxxx   Write hex data at current address and move on"));
  Serial.println(F("Ahhll   Set current address as hhll"));
  Serial.println(F(":xx..   Intel Hex8 format line (type 00=data record)"));
  Serial.println(F("Dxxxx[A] Dump as intel hex data records. xxxx=size, A=Ack"));
}

/* --------------------------------------------- inputLine
Read a line fo text from the Serial Port into input.
Sends "READY" to serial, gets the inpout line.
Returns the first character of the line.
*/
char inputLine() {
  Serial.println("READY");
  while (Serial.available() == 0) {}  //wait for data available
  input = Serial.readString();        //read until timeout
  input.trim();
  input.toUpperCase();
  if (input.length() == 0) return 0;  // empty line
  ix = 1;
  return input.charAt(0);
}

/* --------------------------------------------- nextChar
returns the next character from the input string.
null if no more.
*/
char nextChar() {
  if (ix >= input.length()) return 0;
  return input.charAt(ix++);
}


/* --------------------------------------------- getHex
Read hex value from the input string.
(Tally check sum as we go)
*/
int getHex() {
  int val = 0;
  char h = nextChar();
  char l = nextChar();
  if (h == 0 || l == 0) return -1;  // no more hex digits
  if (h >= '0' && h <= '9') val = (h - '0') * 16;
  if (h >= 'A' && h <= 'F') val = (h - 'A' + 10) * 16;
  if (l >= '0' && l <= '9') val = val + (l - '0');
  if (l >= 'A' && l <= 'F') val = val + (l - 'A' + 10);
  if (val >= 0) {
    sum += val;  // track check sum
  }
  return val;
}

/* --------------------------------------------- setAddress
shifts the address out to the two cascaded shift registers 
*/
void setAddress(int adr) {
  shiftOut(SHIFT_DATA, SHIFT_CLK, MSBFIRST, (adr >> 8));
  shiftOut(SHIFT_DATA, SHIFT_CLK, MSBFIRST, adr);
}

/* --------------------------------------------- inactive
make all control lines inacctive (high)
*/
void inactive() {
  digitalWrite(EE_nOE, 1);
  digitalWrite(EE_nWE, 1);
  digitalWrite(EE_nCC, 1);
}

/* --------------------------------------------- readyToRead
prepare to read from the port, change to READ mode
*/
void readyToRead() {
  // keep control lines inactive
  inactive();
  // set up the data pins for input
  if (mode != MODE_READ) {
    for (int p = EE_D0; p <= EE_D7; p++) {
      pinMode(p, INPUT);
    }
    mode = MODE_READ;
    delay(DLY_MODE);
  }
}

/* --------------------------------------------- read
Read data from eeprom at the given address 
*/
int read(int adr) {
  setAddress(adr);
  digitalWrite(EE_nOE, LOW);  // read low to enable output
  delay(DLY_WAIT);            // let it settle
  // read pins one-by-one and shift into data
  int data = 0;
  for (int p = EE_D7; p >= EE_D0; p--) {
    data = (data << 1) | digitalRead(p);
  }
  digitalWrite(EE_nOE, HIGH);  // read back high
  delay(DLY_WAIT);             // delay for OE
  return data;
}
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

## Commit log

2024-11-11 Added Arduino section
2024-11-19 Removed large install file for kicad-8.0.6-x86_64.exe
    Former-commit-id: 00c60aa45879fdb8a15821be57ce837079a9e464
2024-12-12 Clock Circuit
2025-02-10 batch job for UltraEdit to assemble (using uz80as) and convert output
2025-02-12 Start Of Device work
2025-03-03 Print of decimal line no working
2025-03-06 Changes to BREAK(n) handling, use with 'animate' Initial implementation of PRINT Indented echo info to make Assembler Messages stand out more
2025-03-06 Fix Print Number
2025-03-07 Problem with running PRINT
2025-03-08 Execute of Print fixed :)
2025-03-12 Simple implementation of PRINT
2025-03-16 Multiply seems OK, added brackets
2025-03-18 Load and Save Variables, finished switching to unpacked version internally
2025-03-24 S16 add, sub, parse, print, pushA, popB OK
2025-03-25 Fix print of zero, evaluate of braces
2025-03-27 Added Error handling, refactored display of message (Error and LIST share the same message print routine) Added char/hex substitution in the messages
2025-04-09 PRINT not working
2025-04-10 Print fixed
2025-04-10 fix XRun - bug in print when line ends with ';'
2025-04-10 fixes to print ;
2025-04-14 Fix print of 0
2025-04-14 Implemented Function frame work, SQR(x) and RND(x) RND(x) code has a bug, gets stuck at 313 .. See NumRnd
2025-04-17 Bug in PRINT
2025-05-05 Implemented device number re-routing of I/O
2025-05-05 Implemented simulated serial port ComSim.a65, add #n to PRINT and INPUT
2025-05-08 Fix parsing of decimal for float / error for integer Add 'E' in front of error code Add 'error.' to end of error message Refactor handling of REM Check for decimals in PRINT
2025-09-26 Added RST switch and address connector
    [Retro.kicad_pcb, Retro.kicad_sch]
2025-09-28 Save point
    [Retro.kicad_pcb, Retro.kicad_sch]
2025-11-26 3d model and moved trim pot
    [Mk3.kicad_pcb, Mk3.kicad_sch]
2025-11-26 updated silk & foot prints
    [Mk3.kicad_pcb, Mk3.kicad_sch]
2025-12-12 Minimal Main board
    [Mk4.kicad_sch]
2026-01-13 Added Mk4 (from retor) to add expansion bus as well
    [Mk5.kicad_pcb, Mk5.kicad_sch]
2026-01-13 Added descriptions of each board variant
2026-01-19 Latest variation
    [Mk3.kicad_pcb, Mk3.kicad_sch, Mk4.kicad_sch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]
2026-01-22 all done, pre-clk div
    [com.kicad_sch, core.kicad_sch, io.kicad_sch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]
2026-01-26 Added LCD cap
    [power.kicad_sch]
2026-01-26 Added PCB file
    [Mk6.kicad_pcb]
2026-01-30 Pre Remap
    [Mk6.kicad_pcb, core.kicad_sch, power.kicad_sch]
2026-01-30 Added 3-8 IO, extra GAL out, attachment point for !RAM
    [Mk6.kicad_pcb, com.kicad_sch, core.kicad_sch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]
